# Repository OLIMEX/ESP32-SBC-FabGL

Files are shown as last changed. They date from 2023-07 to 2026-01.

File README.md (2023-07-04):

# ESP32-SBC-FabGL
ESP32-WROVER board working with FabGL library

Software used our fork of FabGL: https://github.com/OLIMEX/FabGL

Product page: https://www.olimex.com/Products/Retro-Computers/ESP32-SBC-FabGL/open-source-hardware

## License
* Hardware is released under CERN OHL v1.2 license
* Software is released under GPL3 License
* Documentation is released under CC BY-SA 3.0

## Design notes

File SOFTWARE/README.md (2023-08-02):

[Firmware_CH32V003](Firmware_CH32V003/) folder contains the source of the firmware preloaded on CH32V003 chip.

[CH32V003_Driver](CH32V003_Driver/) folder contains source of the driver needed to communicate with CH32V003 chip. This driver is used on ESP32 side. Examples of its usage will be uploaded soon.

[FabGL_Nunchuk](FabGL_Nunchuk/) folder contains source of device driver to use WiiNunchuk device with FabGL library. It is in fabgl namespace. Example of its usage can be found in our FabGL fork. It will be pull-requested to Fabio's repository.

[FabGL_PCEmulator](FabGL_PCEmulator/PCEmulator/) folder contains modified source of the PCEmulator application which allows usage of GPIO, I2C and SPI from QBasic and Turbo Pascal 7.0.

[FabGL_Basic](FabGL_Basic/) folder contains source of QBasic examples of usage of GPIOs, I2C and SPI located on UEXT connector. These examples are intended to be used from the PCEmulator application.

[FabGL_Pascal](FabGL_Pascal/) folder contains source of Turbo Pascal 7.0 examples of usage of GPIOs, I2C and SPI located on UEXT connector. These examples are intended to be used from the PCEmulator application.

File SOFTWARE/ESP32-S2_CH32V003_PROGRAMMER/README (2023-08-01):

# Flash ESP32-S2 with CH32v003programmer firmware:
esptool.py -p <PORT> -b 460800 --before=no_reset --after=no_reset write_flash --flash_mode dio --flash_freq 80m --flash_size 4MB 0x1000 ./bootloader.bin 0x10000 ./usb_sandbox.bin 0x8000 ./partition-table.bin

# All bin files were built using sources from:
# https://github.com/cnlohr/esp32s2-cookbook/tree/master/ch32v003programmer

# Flashing CH32V003 using minichlink:
minichlink -w <firmware.bin> 0x08000000 -b

# You can download minichlink from:
# https://github.com/cnlohr/ch32v003fun

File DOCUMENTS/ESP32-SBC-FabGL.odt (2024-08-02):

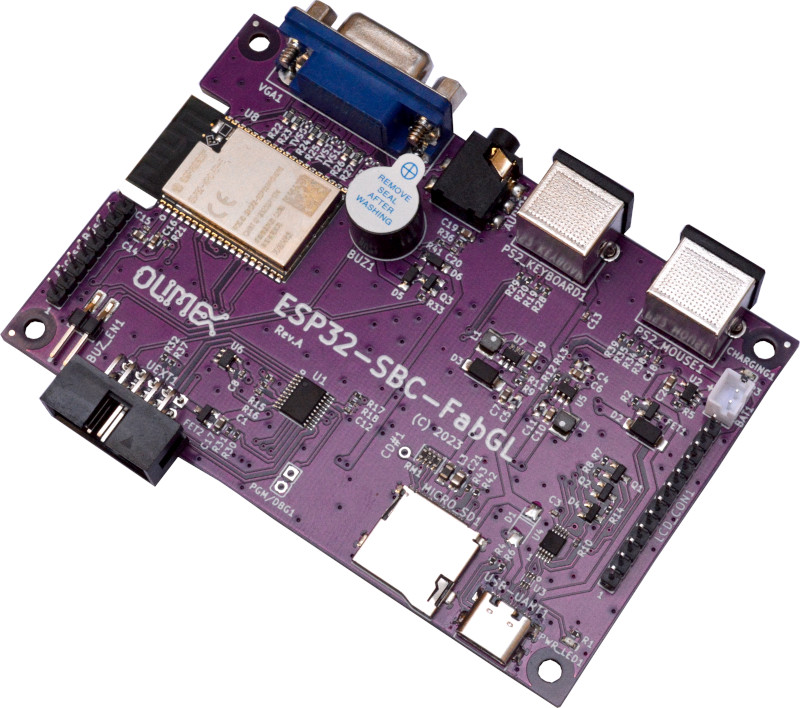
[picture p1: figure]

ESP32-SBC-FabGL

User Manual

Document v3.0 July 2024 olimex.com

# Introduction to ESP32-SBC-FabGL

ESP32-SBC-FabGL (https://www.olimex.com/Products/Retro-Computers/ESP32-SBC-FabGL/open-source-hardware) is Open Source Hardware board designed to work with FabGL library. The board has the following features:

- ESP32-WROVER-E module
- VGA connector
- PS2 keyboard connector
- PS2 mouse connector
- Buzzer
- Audio 3.5mm connector
- AccessBus connector for Serial port master processor
- LCD connector (FabGL support LCD or VGA output)
- CH32V003 co-processor for UEXT port handling
- USB-C power and programming/debug connector
- SY8089A 3.3V 2A (3A peak) DCDC power supply
- Lipo charger and battery connector
- UEXT connector (pUEXT 1.0 mm step connector)
- Dimensions: (104 x 68)mm

## Order codes for ESP32-SBC-FabGL and accessories

ESP32-SBC-FabGL (https://www.olimex.com/Products/Retro-Computers/ESP32-SBC-FabGL/open-source-hardware) FabGL board with VGA keyboard mouse

BOX-ESP32-FabGL (https://www.olimex.com/Products/Retro-Computers/BOX-ESP32-FabGL/) Custom plastic box

CABLE-USB-A-C-1M (https://www.olimex.com/Products/Components/Cables/CABLE-USB-A-C-1M/) USB-C cable 1 meter

BATTERY-LIPO1400mAh (https://www.olimex.com/Products/Power/Lipo-battery/BATTERY-LIPO1400mAh/) Li-po battery 3.7V 1400mAh

UEXT modules (https://www.olimex.com/Products/Modules/) We have temperature, humidity, pressure, magnetic field, light sensors. Modules with LCDs, LED matrix, Relays, Bluetooth, Zigbee, WiFi, GSM, GPS, RFID, RTC, EKG, sensors and etc.

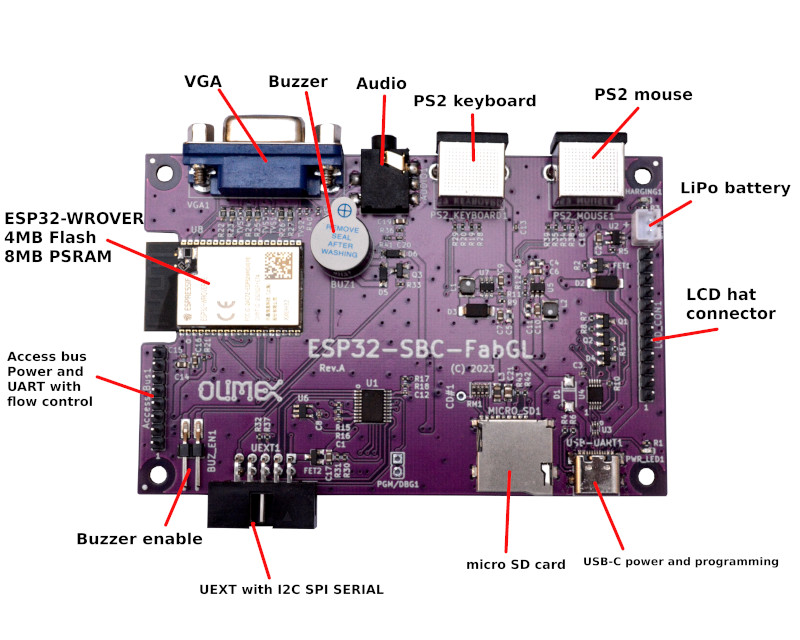
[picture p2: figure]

# HARDWARE

## ESP32-SBC-FabGL schematic and sources

Latest schematic is available on next page for viewing. Sources and PDF export are for ESP32-SBC-FabGL (https://www.olimex.com/Products/Retro-Computers/ESP32-SBC-FabGL/open-source-hardware) are available at GitHub (https://github.com/OLIMEX/ESP32-SBC-FabGL). The page after the schematic shows the dimensions.

At the GitHub pages for the board you can also find schematics for older hardware revisions and also hardware revision change notes (detailing notable changes between revisions).

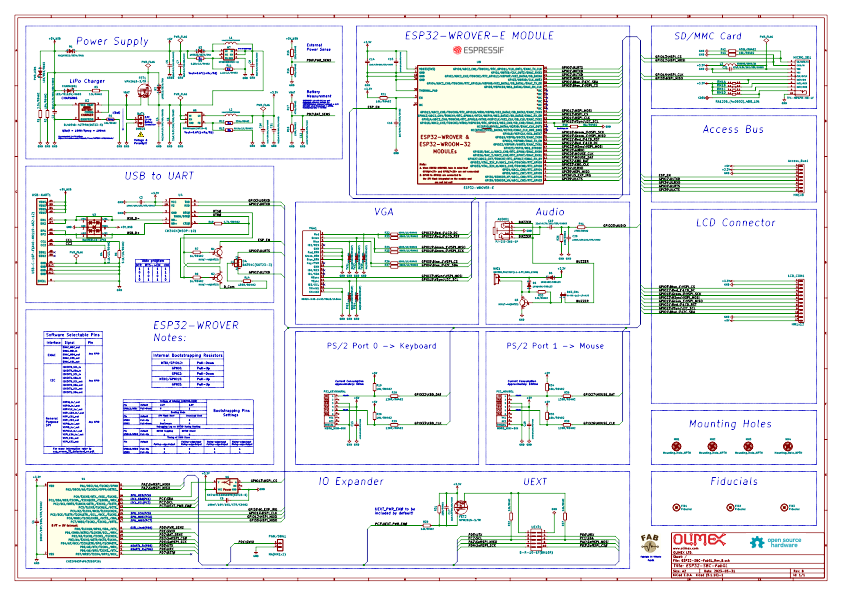
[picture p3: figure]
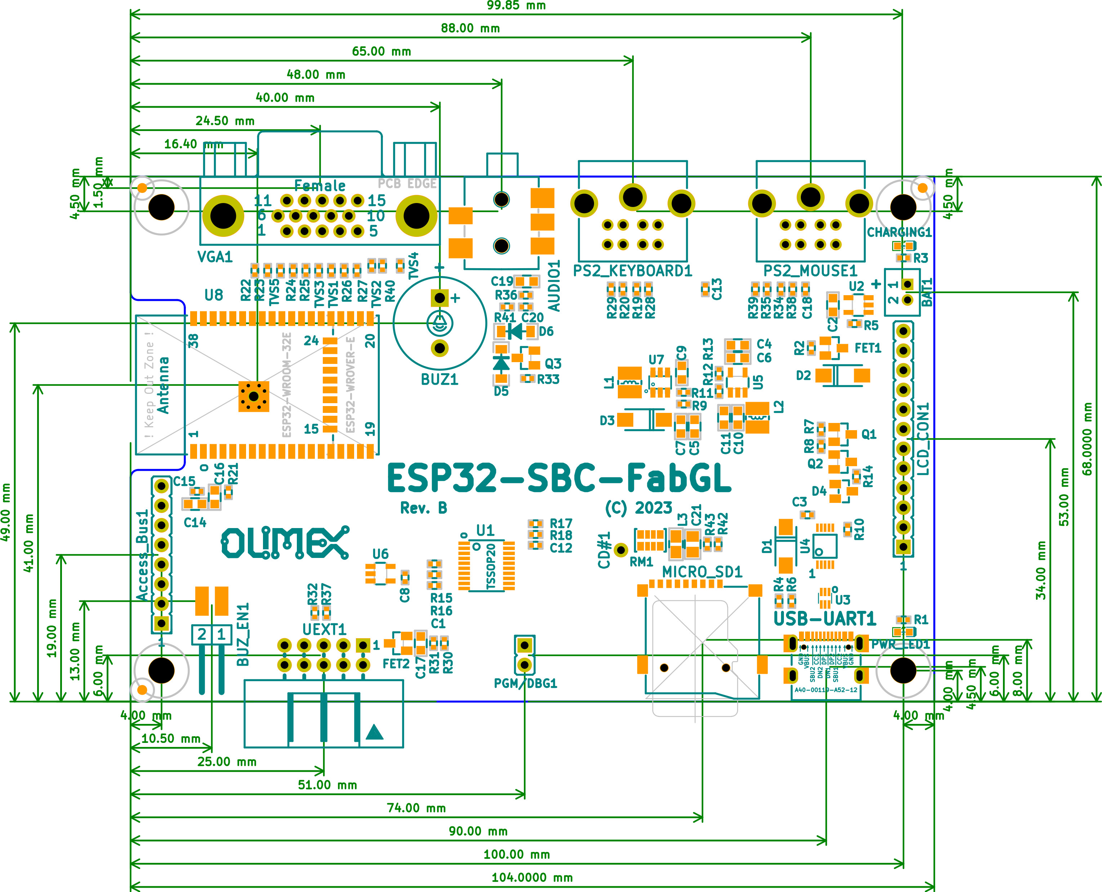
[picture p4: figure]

## UEXT connector:

UEXT connector stands for Universal EXTension connector and contain +3.3V, GND, I2C, SPI, UART signals. UEXT connector can be in different shapes and sizes but the original UEXT connector is 0.1” 2.54mm step boxed plastic connector. All signals are at 3.3V levels.

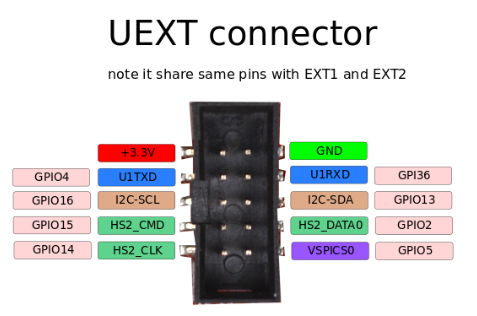
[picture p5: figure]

As the boards become smaller and smaller some smaller packages were introduced (beside the original UEXT connector):

- mUEXT is 1.27 mm step boxed header connector which is with same layout as UEXT

- pUEXT is 1.0 mm single row connector (this is the connector used in RP2040-PICO30)

Olimex has developed number of MODULES (https://www.olimex.com/Products/Modules/) with this connector. There are temperature, humidity, pressure, magnetic field, light sensors. Modules with LCDs, LED matrix, Relays, Bluetooth, Zigbee, WiFi, GSM, GPS, RFID, RTC, EKG, sensors and etc.

## AccessBus connector:

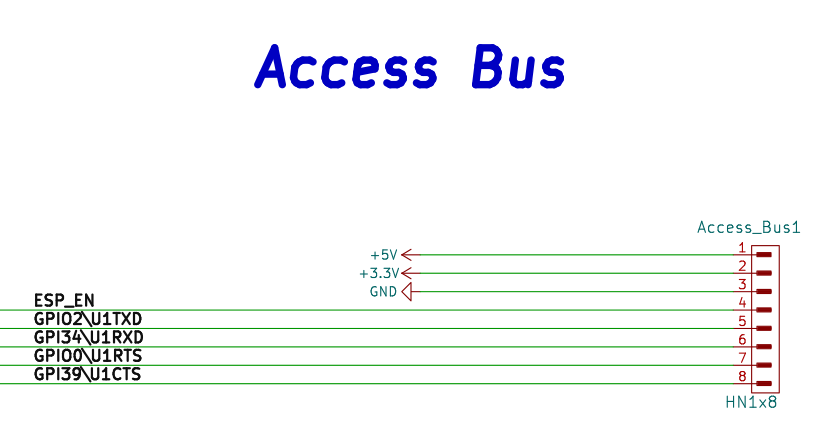
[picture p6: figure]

Pin1. is marked with a square pad, all others are round pads.

## LCD hat connector:

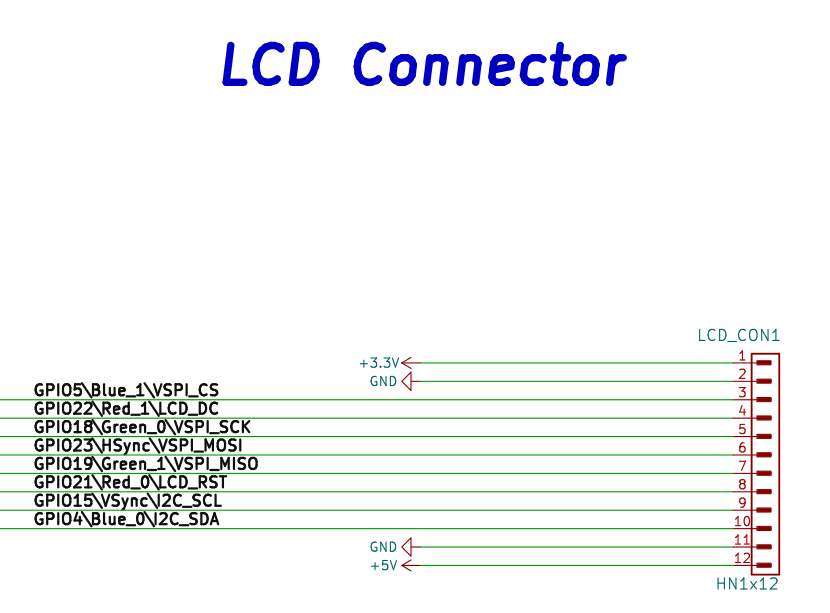
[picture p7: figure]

Pin1. is marked with a square pad, all others are round pads.

# SOFTWARE

ESP32-SBC-FabGL (https://www.olimex.com/Products/Retro-Computers/ESP32-SBC-FabGL/open-source-hardware) is tested and works with many projects, start with the Olimex fork of FabGL project: https://github.com/OLIMEX/FabGL and make sure to check the resources here:

https://github.com/OLIMEX/ESP32-SBC-FabGL/tree/main/SOFTWARE

and here:

https://github.com/OLIMEX/FabGL

## How to get the board working in Arduino IDE?

Set up the Arduino environment

1. Install and start Arduino IDE, get it from: https://www.arduino.cc/en/software

2. Add the esp32 board support by Espressif using the Board Manager (Tools > Board > Board Manager and search for "esp32"). Use the package called “esp32” by Esoressif Systems and use the version selector to load a version 2.x.x! IMPORTANT! At the time of writing this, the FabGL library is NOT compatible with version 3.x.x or newer of the package. From the drop-down menu select version 2.0.x, we used 2.0.11.

3. The Olimex fork of FabGL adds support for the ESP32-SBC-FabGL board and needs to be installed as a local library. You'll also need to first uninstall Fabrizio's FabGL library if it's already installed.

- Go to the Olimex FabGLrepo at GitHub: https://github.com/OLIMEX/FabGL
- Click "Download ZIP" from the green "Code" drop-down button, top-right. Save the ZIP file as "Olimex-FabGL.zip" so you don't get confused with Fabrizio's library and repo.
- Unzip and copy the contents to a new folder in the "Documents\Arduino\libraries" folder (e.g. "C:\Users\username\Documents\Arduino\libraries\Olimex-FabGL").

4. Close Arduino IDE. The next time the IDE is started, the local Olimex FabGL library will be available for use.

Compile and download examples to ESP32-SBC-FabGL

1. Connect the ESP32-SBC-FabGL board to your desktop PC using a USB cable. The USB-C port on the board serves as both power and data.

2. Start Arduino IDE.

3. Verify the Olimex FabGL library is loaded by:
- Opening the Library Manager (Tools > Manage Libraries).
- Typing "FabGL" in to the "filter" textbox.
- Changing the "Type" to "Installed".
- It should list "FabGL 1.0.9" (at the time of this writing) as one of the installed libraries.

4. Select a FabGL demo from (File > Examples > FabGL). The FabGL examples will be at the bottom of a lengthy list.

5. Configure the board.
- Select the "ESP32 Dev Module" board (Tools > Board > esp32 > ESP32 Dev Module).
- Set the board port to upload to (Tools > Port > COM#).
- Set the partition scheme (Tools > Partition > Huge APP).
- Disable PSRAM (Tools > PSRAM > Disabled).
- Set the Upload Speed (Tools > Upload Speed > 921600).
- If an upload error occurs, lower the transfer speed.

6. Edit the demo if needed. Most demos are well-commented on what has to be edited. Some demos require also preparing an SD card or else in specific manner.

7. Compile and upload to the board (Sketch > Upload).

- If all goes well, the ESP32-SBC-FabGL board will reboot after the compilation and upload complete.
- If the wireless parameters were not set, a prompt asking to configure the wireless connection will appear.
- After that, the boot menu should show.

If you have compilation problems with most of the examples you probably installed latest version of espressif package for ESP32. The most important part is to use ESP32 package version older than 3.x.x ESP32 package (we used Espressif 2.0.11). Also do NOT use the “Arduino ESP32 Boards” package! Use the “esp32” package by espressif systems!

## Wordpress articles

Also make sure to check these FabGL articles at our wordpress:

- https://olimex.wordpress.com/2023/06/27/esp32-sbc-fabgl-update-now-you-can-play-invaders-with-wii-nunchuck-via-the-uext-port/

- https://olimex.wordpress.com/2023/08/01/esp32-sbc-fabgl-how-to-work-with-the-expander-module-gpios-from-fabgl-library-and-apps/

- https://olimex.wordpress.com/2023/05/31/zx-espectrum-emulator-tested-with-esp32-sbc-fabgl-the-mensch-computer-with-w65c256-got-vga-display-and-keyboard/

- https://olimex.wordpress.com/2023/05/25/new-open-source-hardware-design-is-verified-esp32-sbc-fabgl-single-board-computer-based-on-fabgl-library-with-ps2-keyboard-mo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

Other projects that we haven’t tested fully but should work:

https://github.com/uho/ESP32forthStation

https://github.com/OulanB/OricVGA32

https://github.com/guidol70/RunCPM_VGA32

https://github.com/EremusOne/ZX-ESPectrum-IDF

https://github.com/rpsubc8/ESP32TinyMCUMEesp81

https://github.com/rpsubc8/ESP32TinyNesMaster

https://github.com/rpsubc8/ESP32TinyZXSpectrum

https://github.com/rpsubc8/ESP32TinyFairChild

https://github.com/rpsubc8/ESP32TinyChip8

https://github.com/rpsubc8/ESP32TinyFake86

https://github.com/rpsubc8/ESP32TinyCPC

https://github.com/rpsubc8/ESP32TinyC64

# Document revision history

Revision 1.0 May 2023

Revision 2.0 April 2024

Revision 3.0 July 2024

- added Arduino IDE installation instructions

- added dimensions

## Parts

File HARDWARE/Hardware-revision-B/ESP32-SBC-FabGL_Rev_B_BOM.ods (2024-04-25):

Qty | Designation | Package | Designator
4 | 120R/R0402 | R_0402_5MIL_DWS | R28,R29,R38,R39
2 | 150R/R0402 | R_0402_5MIL_DWS | R14,R36
1 | 270R/R0402 | R_0402_5MIL_DWS | R41
3 | 430R/1%/R0402 | R_0402_5MIL_DWS | R22,R24,R26
3 | 866R/1%/R0402 | R_0402_5MIL_DWS | R23,R25,R27
2 | 1k/R0402 | R_0402_5MIL_DWS | R7,R8
1 | 1.1k/1%/R0402 | R_0402_5MIL_DWS | R11
6 | 2.2k/R0402 | R_0402_5MIL_DWS | R1,R3,R30,R32,R37,R33
1 | 4.7k/R0402 | R_0402_5MIL_DWS | R10
2 | 5.1k/1%/R0402 | R_0402_5MIL_DWS | R4,R6
1 | 8.25k/1%/R0402 | R_0402_5MIL_DWS | R9
8 | 10k/R0402 | R_0402_5MIL_DWS | R2,R5,R19,R20,R21,R34,R35,R43
1 | 49.9k/1%/R0402 | R_0402_5MIL_DWS | R13
1 | 150k/R0402 | R_0402_5MIL_DWS | R18
3 | 220k/R0402 | R_0402_5MIL_DWS | R12,R15,R31
3 | 470k/R0402 | R_0402_5MIL_DWS | R16,R17,R42
1 | RA1206_(4x0603)_4B8_10k | RA1206_(4X0603)_4B8_xx | RM1
8 | 100nF/10V/10%/X7R/C0402 | C_0402_5MIL_DWS | C1,C3,C8,C12,C13,C15,C18,C20
1 | 1uF/10V/20%/X5R/C0603 | C_0603_5MIL_DWS | C16
8 | 22uF/6.3V/20%/X5R/C0603 | C_0603_5MIL_DWS | C2,C6,C7,C9,C10,C14,C17,C19
1 | 47uF/6.3V/20%/X5R/C0805 | C_0805_5MIL_DWS | C21
1 | 2.2uH/NRS3015T2R2MNGH | CD32 | L1,L2
1 | FB0805/600R/2A | L_0805_5MIL_DWS | L3
2 | 1N5822/SS34/SMA | SMA-KA | D2,D3
2 | 1N4148W/SOD123 | SOD-123_1C-2A_KA | D5,D6
1 | BAT54C(SOT23-3) | SOT23-3 | D4
1 | LED/RED/0603 | LED_0603_KA | PWR_LED1
1 | LED/YELLOW/0603 | LED_0603_KA | CHARGING1
3 | BC817-40(SOT23) | SOT23 | Q1,Q2,Q3
2 | WPM2015-3/TR | SOT23 | FET1,FET2
1 | CH32V003F4P6(TSSOP20) | TSSOP20_Pitch-0.65mm_6.6x4.5x1.2mm | U1
1 | BL4054B-42TPRN(SOT23-5) | SOT-23-5 | U2
1 | CH340X(MSOP-10) | MSOP-10_Pitch-0.5mm_3.00x3.00x1.00mm | U4
1 | SY8089AAAC(SOT23-5) | SOT-23-5 | U5
1 | MT3608(SOT23-6) | SOT23-6 | U7
1 | ESP32-WROVER-E | ESP32-WROVER)-UNIVERSAL_MODULE | U8
1 | SN74LVC1G04DBVR(SOT23-5) | SOT-23-5 | U6
1 | PJ-3.5-365-5P | SCJ325P00XG0B02G | AUDIO1
1 | DW02S | LIPO_BAT_VERTICAL_DW02S | BAT1
1 | BUZZER_PB1221P (1.1-1.7V_2kHz_12MM) | PB1221P_1-Plus_2-Minus | BUZ1
1 | TFC-WPAPR-08-LF | TFC-WPAPR-08 | MICRO_SD1
2 | MDR6_MINI-DIN | PS2_MDR6_MINI-DIN | PS2_KEYBOARD1,PS2_MOUSE1
1 | HDR15-3.08-14.5T/VGA15/14.5mm | VGA15-F(HDR15-3.08-14.5T) | VGA1
1 | USB-C-16P-F(A40-00119-A52-12) | USB2.0_TYPE-C(A40-00119-A52-12)_Paste | USB-UART1
1 | B-R-10-LF(BH10R) | BH10R | UEXT1
1 | HN1x8 | HN1x8 | Access_Bus1
1 | HN1x12 | HN1x12 | LCD_CON1
1 | H-WX-1x2-LF+MJ6 | HN1x2(SMD)_H-WX-1x2-LF | BUZ_EN1
3 | NA(22uF/6.3V/20%/X5R/C0603) | C_0603_5MIL_DWS | C11,C4,C5
5 | NA(GG0402052R542P) | D_0402_5MIL_DWS | TVS1,TVS2,TVS3,TVS4,TVS5
1 | NA(USBLC6-2P6) | SOT-666 | U3
1 | NA(HN1x2) | HN1x2 | PGM/DBG1
1 | NA(1N5822/SS34/SMA) | SMA-KA | D1
1 | NA/R0402 | R_0402_5MIL_DWS | R40

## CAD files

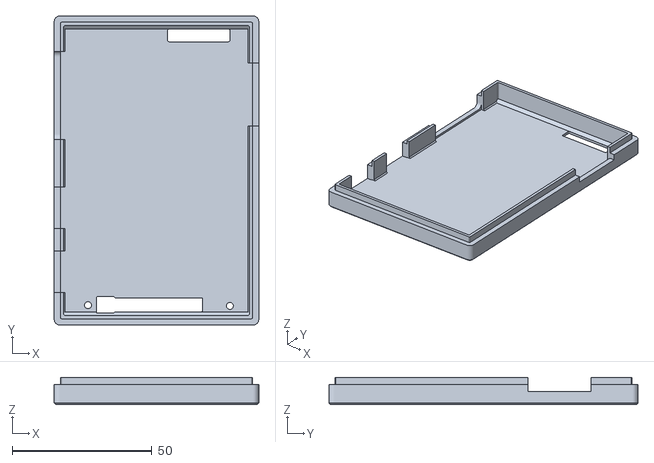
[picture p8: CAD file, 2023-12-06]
HARDWARE/3D printed case/esp32-sbc-fabgl-revsion-A-top-v1.stl
73.1 x 110.4 x 9.80

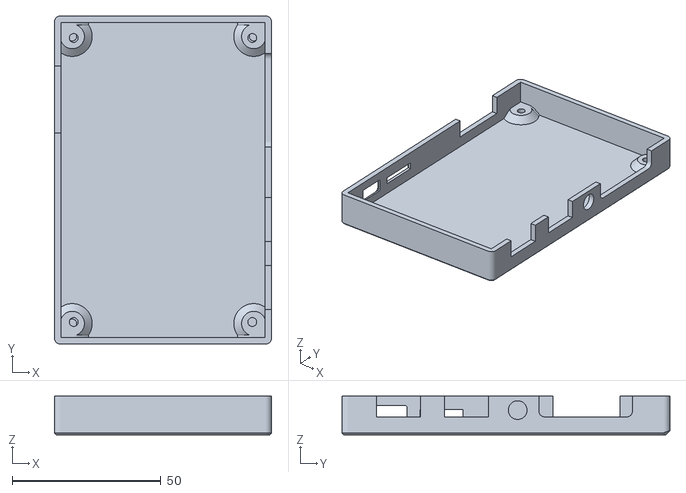
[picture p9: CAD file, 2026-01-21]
HARDWARE/3D printed case/olimex-esp32-fabgl-model_files/esp32-sbc-fabgl_v1-bottom.stl
73.1 x 110.4 x 13.0

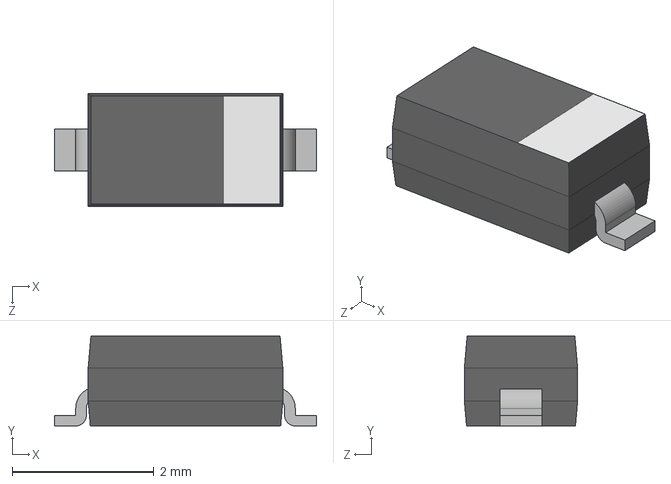
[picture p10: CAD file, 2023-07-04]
HARDWARE/Hardware-revision-B/3d/SOD123.step
3.70 x 1.27 x 1.60 mm

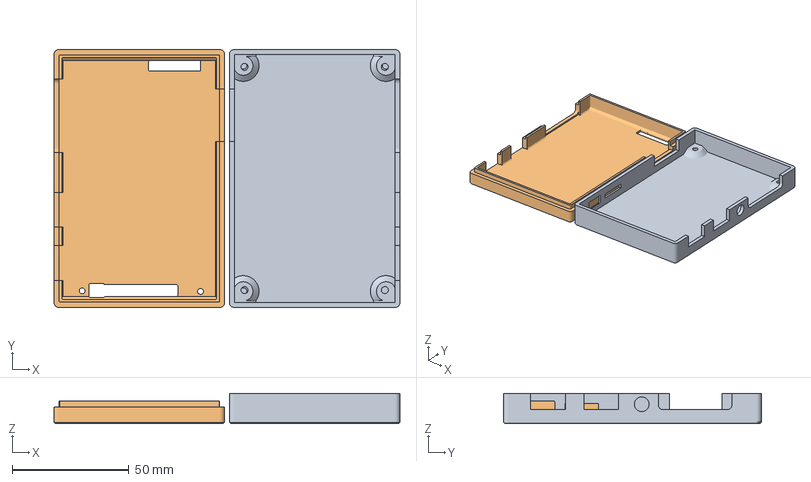
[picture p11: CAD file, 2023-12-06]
HARDWARE/3D printed case/esp32-sbc-fabgl-revsion-A-v1.3mf
148.2 x 110.4 x 13.0 mm
bottom (1) (1)
top (2)

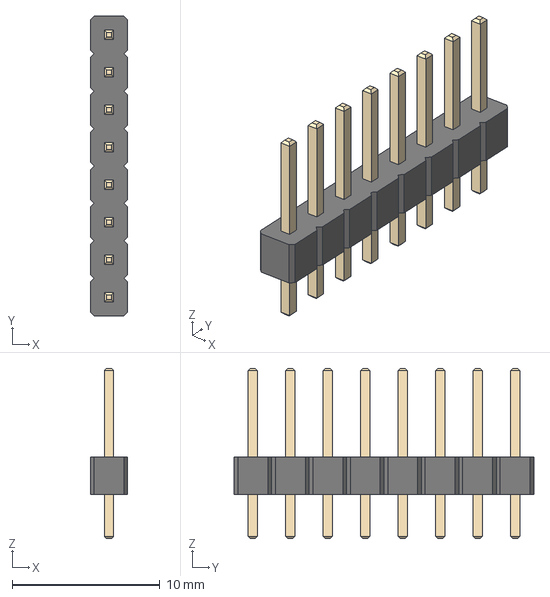
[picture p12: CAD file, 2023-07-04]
HARDWARE/Hardware-revision-B/3d/HN1x8-PinHeader_1x08_P2.54mm_Vertical.step
2.54 x 20.3 x 11.5 mm

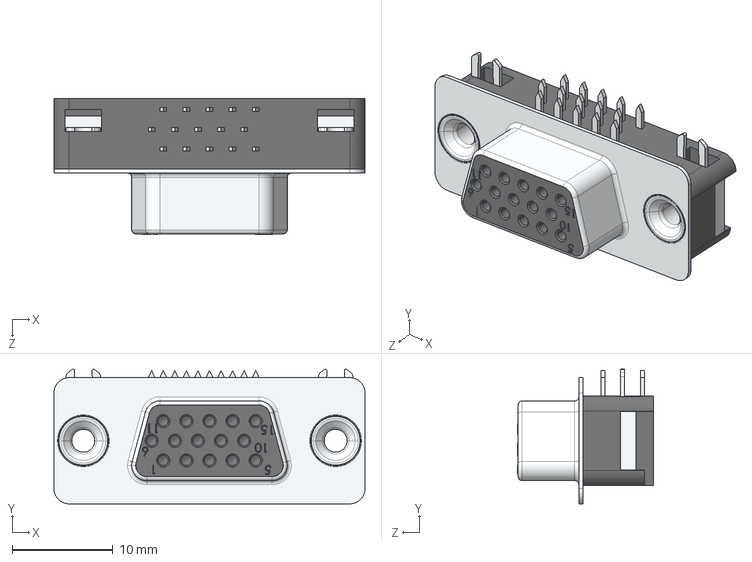
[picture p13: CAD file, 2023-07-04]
HARDWARE/Hardware-revision-B/3d/User Library-SLIM D-SUB RIGHT ANGLE PCB MOUNT.step
30.8 x 13.3 x 13.5 mm

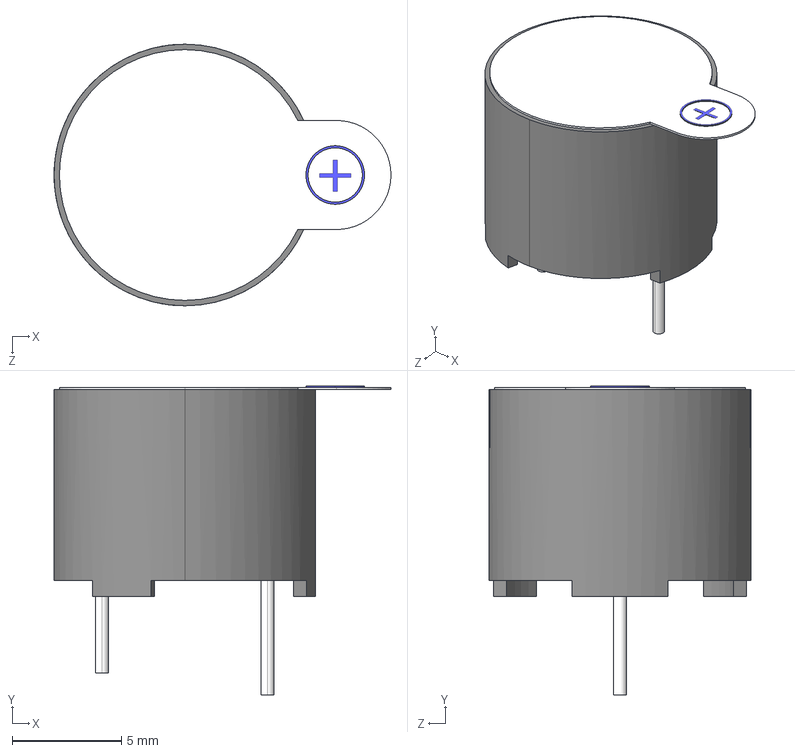
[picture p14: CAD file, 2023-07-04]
HARDWARE/Hardware-revision-B/3d/ALSRobot-BUZZER.step
15.5 x 14.2 x 12.0 mm

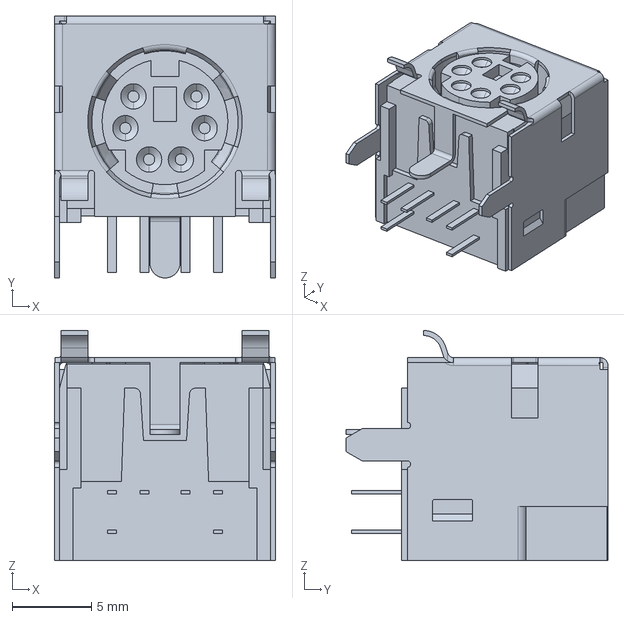
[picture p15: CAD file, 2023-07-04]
HARDWARE/Hardware-revision-B/3d/PS2_MDR6_MINI-DIN(5750071-1).stp
14.0 x 16.6 x 14.5 mm

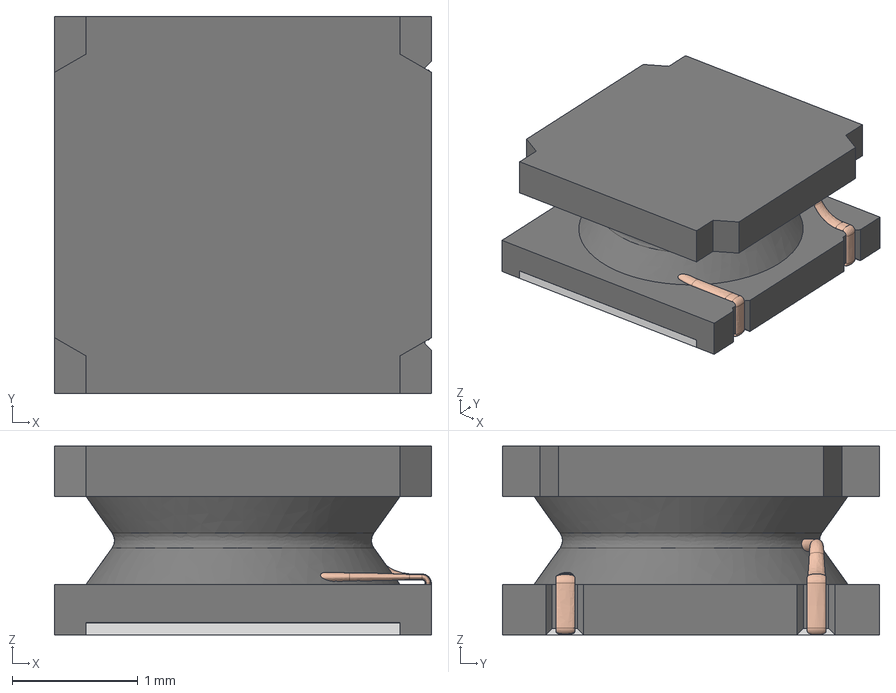
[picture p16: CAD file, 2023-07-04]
HARDWARE/Hardware-revision-B/3d/L-CD32_shielded.step
3.00 x 3.00 x 1.50 mm

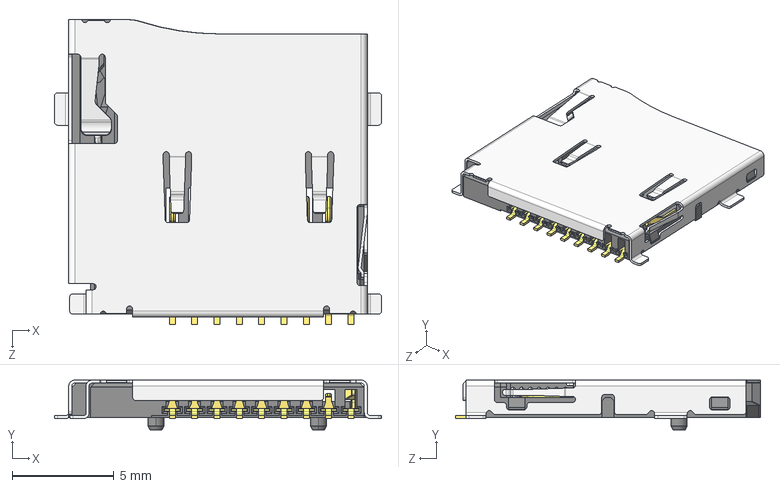
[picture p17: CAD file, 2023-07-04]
HARDWARE/Hardware-revision-B/3d/TFC-WPAPR-08---112J-TXAR-R_C_1-1.STEP
16.1 x 2.45 x 15.0 mm

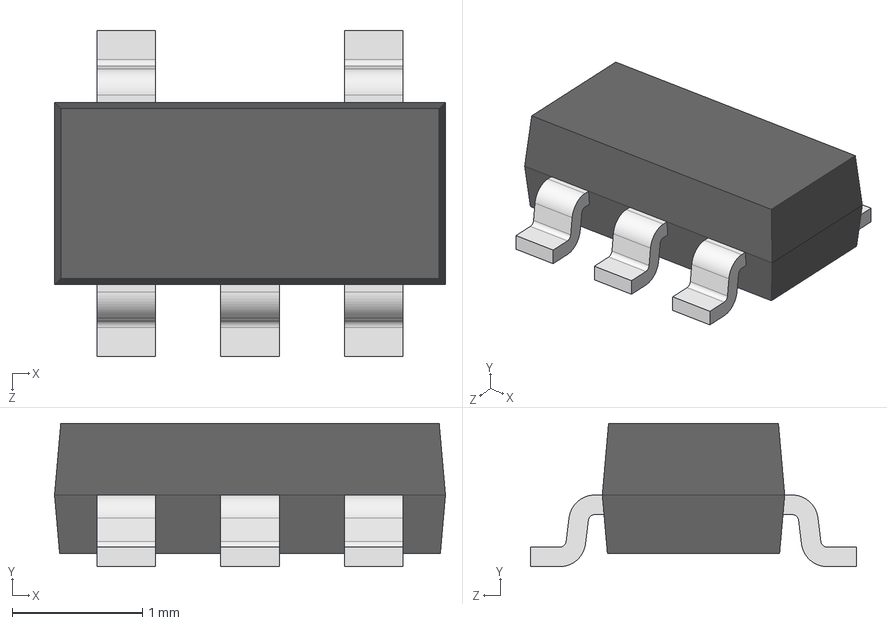
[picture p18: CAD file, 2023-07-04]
HARDWARE/Hardware-revision-B/3d/SOT-23-5.step
3.00 x 1.10 x 2.50 mm

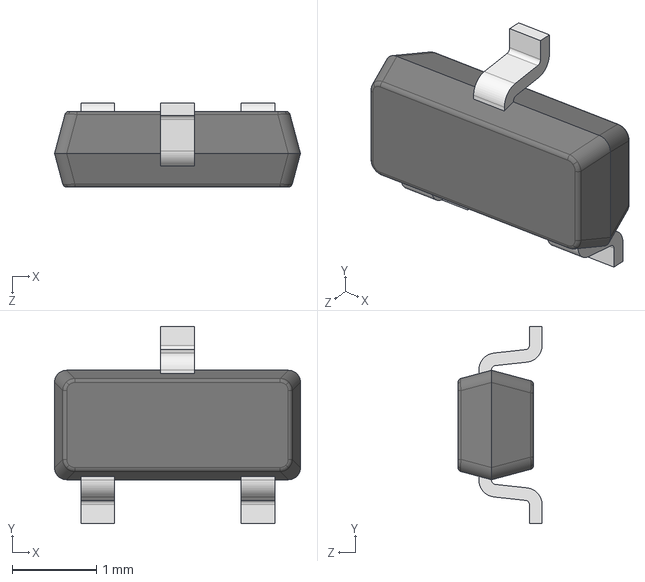
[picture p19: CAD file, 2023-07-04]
HARDWARE/Hardware-revision-B/3d/BAT54.step
2.92 x 2.34 x 1.00 mm

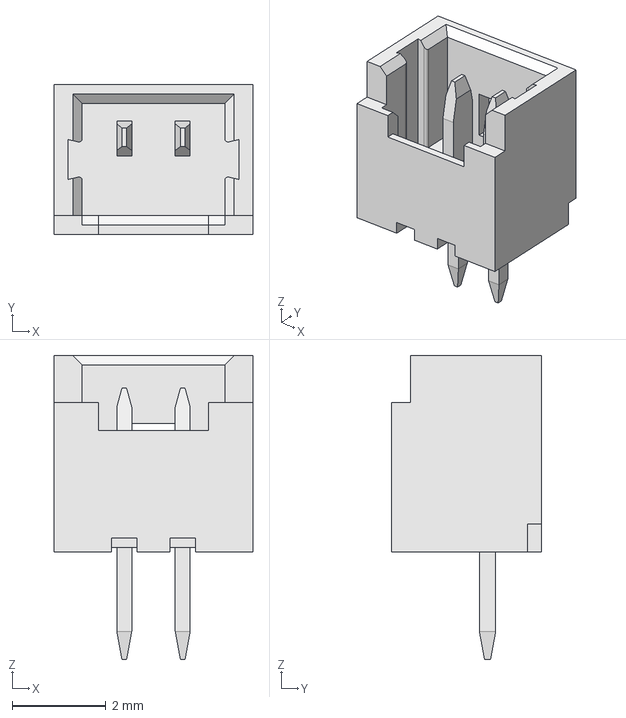
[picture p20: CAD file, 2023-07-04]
HARDWARE/Hardware-revision-B/3d/Molex_PicoBlade_530470210.step
4.25 x 3.20 x 6.50 mm

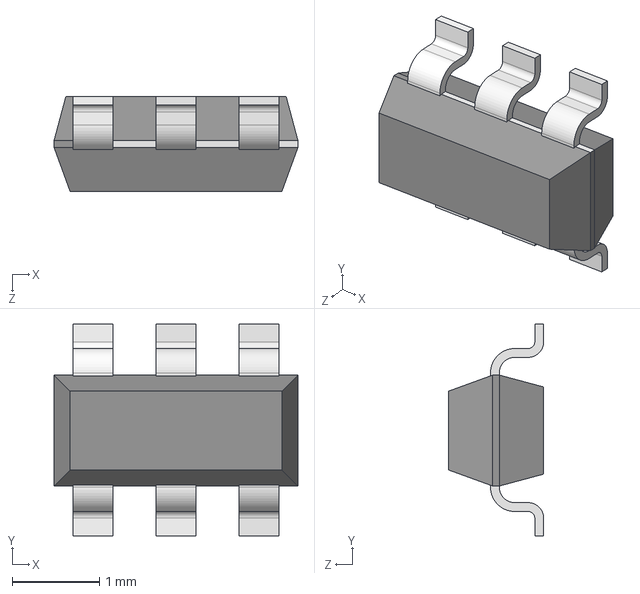
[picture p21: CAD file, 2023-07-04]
HARDWARE/Hardware-revision-B/3d/SOT-23-6.step
2.79 x 2.43 x 1.09 mm

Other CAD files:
HARDWARE/3D printed case/olimex-esp32-fabgl-model_files/esp32-sbc-fabgl_v1-single.3mf
HARDWARE/3D printed case/esp32-sbc-fabgl-revsion-A-bottom-v1.stl
HARDWARE/3D printed case/olimex-esp32-fabgl-model_files/esp32-sbc-fabgl_v1-top.stl
HARDWARE/Hardware-revision-B/3d/DO-214AC_SMA.step
HARDWARE/Hardware-revision-A/3d/Audio_Jack-3.5mm---CUI_SJ1-3515-SMT-TR.step
HARDWARE/Hardware-revision-A/3d/DO-214AC_SMA.step
HARDWARE/Hardware-revision-A/3d/ESP32-WROOM-32D-56544.STEP
HARDWARE/Hardware-revision-A/3d/ESP32-WROVER-I-56544.STEP
HARDWARE/Hardware-revision-A/3d/HN1x12-PinHeader_1x12_P2.54mm_Vertical.step
HARDWARE/Hardware-revision-A/3d/HN1x2-PinHeader_1x02_P2.54mm_Vertical.step
HARDWARE/Hardware-revision-A/3d/Header_right_angle_10way(2x5).step
HARDWARE/Hardware-revision-A/3d/MSOP10-1.step
HARDWARE/Hardware-revision-A/3d/SOT-23.step
HARDWARE/Hardware-revision-A/3d/User Library-SOT50P160X60-6.step
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

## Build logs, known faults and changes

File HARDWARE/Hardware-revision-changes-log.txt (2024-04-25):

Notable hardware changes for ESP32-SBC-FabGL

Notice that the board is designed with KiCAD

---
Hardware revision B (minor changes):

- Added description of Access, Bus, UEXT, and LCD connectors;
- Changed packages of 820R and 430R to 0402;
- Changed value of ESP32 chip to ESP32-WROVER-E;
- Speaker  govoritelq se запазва се като на AgonLight2.
- Improved VGA resistor values 430R changed to 1%.

Hardware revision A:

- initial release

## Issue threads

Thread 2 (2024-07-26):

SpaceInvaders example for ESP32-SBC-FabGL doesn't compile - multiple errors

Andy2No, 2024-07-26:
In trying to compile the SpaceInvaders FabGL example in Arduino 1.8.19, I get multiple errors.  Possibly this is because it's not compatible with ESP Espessif board support v3.0.2, which is the current version.

I started trying to use the main FabGL library, having followed instructions to install that.  I
realised earlier I should have been using Olimex's own fork, so I installed that instead, but that hasn't got me any further.

In order to get the SpaceInvaders.ino example to compile past a certain point, I had to add some missing files, which I've taken from a pending pull request I found in the main FabGL library (now a year old) to add support for the ESP32-SBC-FabGL.  I copied these files into the project folder:

 wiiNunchuk.h, wiiNunchuk.cpp, CH32V003.h, CH32V003.cpp

I got them from here:

https://github.com/fdivitto/FabGL/pull/338

I now get the errors below, which seem to suggest that your example and possibly FabGL fork aren't compatible with ESP 3.0.2 - and it seems neither is the main FabGL library.  The one I bought came with SpaceInvaders isntalled, so I know it's possible, but I can't find any clues how to get it to compile, specifically which versions to use.  I tried ESP v2.0.17 in the boards manager, but that removed support for the ESP32-SBC-FabGL board.  I'm now wondering if it's still even possible to compile FabGL examples, justifying the FabGL part of the name.

Here are the error messages.  Let me know if you need the full compilation log:

```
D:\Documents\Arduino\libraries\FabGL-master\src\fabutils.cpp: In function 'void fabgl::configureGPIO(gpio_num_t, gpio_mode_t)':
D:\Documents\Arduino\libraries\FabGL-master\src\fabutils.cpp:203:19: error: 'GPIO_PIN_MUX_REG' was not declared in this scope; did you mean 'GPIO_PIN19_REG'?
  203 |   PIN_FUNC_SELECT(GPIO_PIN_MUX_REG[gpio], PIN_FUNC_GPIO);
      |                   ^~~~~~~~~~~~~~~~
      |                   GPIO_PIN19_REG
D:\Documents\Arduino\libraries\FabGL-master\src\fabutils.cpp:203:43: error: 'PIN_FUNC_GPIO' was not declared in this scope
  203 |   PIN_FUNC_SELECT(GPIO_PIN_MUX_REG[gpio], PIN_FUNC_GPIO);
      |                                           ^~~~~~~~~~~~~
D:\Documents\Arduino\libraries\FabGL-master\src\fabui.cpp: In member function 'void fabgl::uiApp::killTimer(fabgl::uiTimerHandle)':
D:\Documents\Arduino\libraries\FabGL-master\src\fabui.cpp:948:50: error: invalid conversion from 'fabgl::uiTimerHandle' {aka 'void*'} to 'TimerHandle_t' {aka 'tmrTimerControl*'} [-fpermissive]
  948 |   auto dest = (uiEvtHandler *) pvTimerGetTimerID(handle);
      |                                                  ^~~~~~
      |                                                  |
      |                                                  fabgl::uiTimerHandle {aka void*}
In file included from D:\Documents\Arduino\libraries\FabGL-master\src\fabui.cpp:28:
C:\Users\andy\AppData\Local\Arduino15\packages\esp32\tools\esp32-arduino-libs\idf-release_v5.1-bd2b9390ef\esp32/include/freertos/FreeRTOS-Kernel/include/freertos/timers.h:395:47: note:   initializing argument 1 of 'void* pvTimerGetTimerID(TimerHandle_t)'
  395 | void * pvTimerGetTimerID( const TimerHandle_t xTimer ) PRIVILEGED_FUNCTION;
      |                           ~~~~~~~~~~~~~~~~~~~~^~~~~~
D:\Documents\Arduino\libraries\FabGL-master\src\fabui.cpp:949:44: error: no matching function for call to 'std::pair<fabgl::uiEvtHandler*, tmrTimerControl*>::pair(fabgl::uiEvtHandler*&, void*&)'
  949 |   m_timers.remove(uiTimerAssoc(dest, handle));
      |                                            ^
In file included from c:\users\andy\appdata\local\arduino15\packages\esp32\tools\esp-x32\2302\xtensa-esp32-elf\include\c++\12.2.0\bits\stl_algobase.h:64,
                 from c:\users\andy\appdata\local\arduino15\packages\esp32\tools\esp-x32\2302\xtensa-esp32-elf\include\c++\12.2.0\bits\specfun.h:45,
                 from c:\users\andy\appdata\local\arduino15\packages\esp32\tools\esp-x32\2302\xtensa-esp32-elf\include\c++\12.2.0\cmath:1935,
                 from c:\users\andy\appdata\local\arduino15\packages\esp32\tools\esp-x32\2302\xtensa-esp32-elf\include\c++\12.2.0\math.h:36,
                 from C:\Users\andy\AppData\Local\Arduino15\packages\esp32\hardware\esp32\3.0.2\cores\esp32/esp32-hal.h:30,
                 from C:\Users\andy\AppData\Local\Arduino15\packages\esp32\hardware\esp32\3.0.2\cores\esp32/Arduino.h:36,
                 from D:\Documents\Arduino\libraries\FabGL-master\src\fabutils.h:51,
                 from D:\Documents\Arduino\libraries\FabGL-master\src\fabui.cpp:34:
c:\users\andy\appdata\local\arduino15\packages\esp32\tools\esp-x32\2302\xtensa-esp32-elf\include\c++\12.2.0\bits\stl_pair.h:297:9: note: candidate: 'template<class _U1, class _U2>  requires  _S_constructible<_U1, _U2>() constexpr std::pair<_T1, _T2>::pair(std::pair<_U1, _U2>&&) [with _U2 = _U1; _T1 = fabgl::uiEvtHandler*; _T2 = tmrTimerControl*]'
  297 |         pair(pair<_U1, _U2>&& __p)
      |         ^~~~
c:\users\andy\appdata\local\arduino15\packages\esp32\tools\esp-x32\2302\xtensa-esp32-elf\include\c++\12.2.0\bits\stl_pair.h:297:9: note:   template argument deduction/substitution failed:
D:\Documents\Arduino\libraries\FabGL-master\src\fabui.cpp:949:44: note:   mismatched types 'std::pair<_T1, _T2>' and 'fabgl::uiEvtHandler*'
  949 |   m_timers.remove(uiTimerAssoc(dest, handle));
      |                                            ^
c:\users\andy\appdata\local\arduino15\packages\esp32\tools\esp-x32\2302\xtensa-esp32-elf\include\c++\12.2.0\bits\stl_pair.h:288:9: note: candidate: 'template<class _U1, class _U2>  requires  _S_constructible<const _U1&, const _U2&>() constexpr std::pair<_T1, _T2>::pair(const std::pair<_U1, _U2>&) [with _U2 = _U1; _T1 = fabgl::uiEvtHandler*; _T2 = tmrTimerControl*]'
  288 |         pair(const pair<_U1, _U2>& __p)
      |         ^~~~
c:\users\andy\appdata\local\arduino15\packages\esp32\tools\esp-x32\2302\xtensa-esp32-elf\include\c++\12.2.0\bits\stl_pair.h:288:9: note:   template argument deduction/substitution failed:
D:\Documents\Arduino\libraries\FabGL-master\src\fabui.cpp:949:44: note:   mismatched types 'const std::pair<_T1, _T2>' and 'fabgl::uiEvtHandler*'
  949 |   m_timers.remove(uiTimerAssoc(dest, handle));
      |                                            ^
c:\users\andy\appdata\local\arduino15\packages\esp32\tools\esp-x32\2302\xtensa-esp32-elf\include\c++\12.2.0\bits\stl_pair.h:279:9: note: candidate: 'template<class _U1, class _U2>  requires  _S_constructible<_U1, _U2>() constexpr std::pair<_T1, _T2>::pair(_U1&&, _U2&&) [with _U2 = _U1; _T1 = fabgl::uiEvtHandler*; _T2 = tmrTimerControl*]'
  279 |         pair(_U1&& __x, _U2&& __y)
      |         ^~~~
c:\users\andy\appdata\local\arduino15\packages\esp32\tools\esp-x32\2302\xtensa-esp32-elf\include\c++\12.2.0\bits\stl_pair.h:279:9: note:   template argument deduction/substitution failed:
c:\users\andy\appdata\local\arduino15\packages\esp32\tools\esp-x32\2302\xtensa-esp32-elf\include\c++\12.2.0\bits\stl_pair.h:279:9: note: constraints not satisfied
c:\users\andy\appdata\local\arduino15\packages\esp32\tools\esp-x32\2302\xtensa-esp32-elf\include\c++\12.2.0\bits\stl_pair.h: In substitution of 'template<class _U1, class _U2>  requires  _S_constructible<_U1, _U2>() constexpr std::pair<fabgl::uiEvtHandler*, tmrTimerControl*>::pair(_U1&&, _U2&&) [with _U1 = fabgl::uiEvtHandler*; _U2 = tmrTimerControl*]':
D:\Documents\Arduino\libraries\FabGL-master\src\fabui.cpp:949:44:   required from here
c:\users\andy\appdata\local\arduino15\packages\esp32\tools\esp-x32\2302\xtensa-esp32-elf\include\c++\12.2.0\bits\stl_pair.h:279:2:   required by the constraints of 'template<class _T1, class _T2> template<class _U1, class _U2>  requires  _S_constructible<_U1, _U2>() constexpr std::pair<_T1, _T2>::pair(_U1&&, _U2&&)'
c:\users\andy\appdata\local\arduino15\packages\esp32\tools\esp-x32\2302\xtensa-esp32-elf\include\c++\12.2.0\bits\stl_pair.h:277:45: note: the expression '_S_constructible<_U1, _U2>() [with _U1 = fabgl::uiEvtHandler*&; _U2 = void*&; _T1 = fabgl::uiEvtHandler*; _T2 = tmrTimerControl*]' evaluated to 'false'
  277 |         requires (_S_constructible<_U1, _U2>())
      |                  ~~~~~~~~~~~~~~~~~~~~~~~~~~~^~~
c:\users\andy\appdata\local\arduino15\packages\esp32\tools\esp-x32\2302\xtensa-esp32-elf\include\c++\12.2.0\bits\stl_pair.h:217:9: note: candidate: 'template<class ... _Args1, unsigned int ..._Indexes1, class ... _Args2, unsigned int ..._Indexes2> constexpr std::pair<_T1, _T2>::pair(std::tuple<_Args1 ...>&, std::tuple<_Args2 ...>&, std::_Index_tuple<_Indexes1 ...>, std::_Index_tuple<_Indexes2 ...>) [with _Args1 = {_Args1 ...}; unsigned int ..._Indexes1 = {_Indexes1 ...}; _Args2 = {_Args2 ...}; unsigned int ..._Indexes2 = {_Indexes2 ...}; _T1 = fabgl::uiEvtHandler*; _T2 = tmrTimerControl*]'
  217 |         pair(tuple<_Args1...>&, tuple<_Args2...>&,
      |         ^~~~
D:\Documents\Arduino\libraries\FabGL-master\src\fabutils.cpp:203:3: error: 'PIN_FUNC_SELECT' was not declared in this scope
  203 |   PIN_FUNC_SELECT(GPIO_PIN_MUX_REG[gpio], PIN_FUNC_GPIO);
      |   ^~~~~~~~~~~~~~~
c:\users\andy\appdata\local\arduino15\packages\esp32\tools\esp-x32\2302\xtensa-esp32-elf\include\c++\12.2.0\bits\stl_pair.h:217:9: note:   template argument deduction/substitution failed:
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
DanKoloff, 2024-08-01:
Did you stumble upon this:

https://github.com/MrSoxAndShoes/esp32-sbc-fabgl-quick-start

Andy2No, 2024-08-01:
Thanks very much, DanKoloff.  I'm now able to compile the PC Emulator with those settings, and the v2.0.11 of ESP32 boards support recommended there.   I'll try it out later.

The main pieces that were missing from what I've been able to find in this repo were:

```
Espressif 2.0.11
Select the "ESP32 Dev Module" board (Tools > Board > esp32 > ESP32 Dev Module)
```

The Espressif 2.0.11 part being which board support package to select in the Arduino IDE boards manager, and the second part being which board type to choose, when compiling one of the examples (including the PC emulator).

I'd like to suggest that this needs to be added to the documentation for this board, perhaps to the readme pages of the two repos - this one, specifically about this board, and the one for the Olimex fork of FabGL (https://github.com/OLIMEX/FabGL).  Perhaps added to the product page on the Olimex website too, and ideally to the manual.

It seems this problem has been around since at least the release of Espressif 3.0.x, though I'm not clear when that was.  The existing documentation was no doubt fine at the time of release, but the fact that Espressif chose to break support for software written for their earlier versions, means it's no longer enough.

FWIW, in Arduino 1.8.19, it seems necessary to uninstall Espressif 3.0.2 (the current version) before installing 2.0.11.  Possibly it keeps both, otherwise, but shows the greater version number, which is a bit confusing.

DanKoloff, 2024-08-02:
Thank you for the feedback. Some resources were updated, how-to was added in the README here:

https://github.com/OLIMEX/FabGL/blob/master/README.md

and the manual was also updated:

https://github.com/OLIMEX/ESP32-SBC-FabGL/blob/main/DOCUMENTS/ESP32-SBC-FabGL.pdf

Andy2No, 2024-08-02:
You're welcome, @DanKoloff .

Yes, that should do it.  I think the advice to set;

```
Partition Scheme: Huge APP
```

was just for the PC Emulator, but I've tried compiling the SpaceInvaders.ino example with those settings and it works fine, so maybe it doesn't matter for the other examples.  I'll try some more of them soon.

Thanks again.

DanKoloff, 2025-05-04:
Now that I think about it, the issue here was that neither of the official releases are suitable and Olimex version of FabGL had to be used as described here:

https://github.com/OLIMEX/ESP32-SBC-FabGL/issues/4#issuecomment-2829673158

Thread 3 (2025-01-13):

Unable to get Olimex FabGL board to respond on USB-C serial

shawty, 2025-01-13:
I've followed the instructions in the User Guide PDF to get my FabGL board connected to and programmed from my Arduino IDE, but no matter what I try I just keep ending up with this:

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

The device shows up with a proper serial port and no errors in my Device manager:

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

and I have the correct board library:

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

and FabGL version installed into my IDE:

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

Arduino tools menu is as expected:

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

I started at the highest speed, and got slower and slower, but nothing made any difference.

I know that my Arduino IDE as it is set up can program ESP32 boards, as I have 2 standard WRoom32's and an S3 here and I can plug both of those in and program them with no issue.

I've even tried shorting together the "PGM/DBG1" link on the board and re-tested, but again, no matter what, I just get a "No serial response from board"

My board has arrived from PiHut with "Space Invaders" already programmed onto it, and when I try to program the board I see the board re-boot as expected, but it always restarts in space invaders and never uploads my own sketch.

Sketches I'm trying to upload so far as well as my own are the examples from the Olimex Fab32 distro, and all fail the same way.

Any advice?

Andy2No, 2025-01-13:
@shawty You may need to install the driver for the CH340.

Here's a link for Windows 10.  There are other versions:
https://www.arduined.eu/tag/ch340g/

shawty, 2025-01-13:
Hi Andy, I already have that driver installed:

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

I will however grab the latest one I do an update, see if it makes any difference.

Thanks.

DanKoloff, 2025-01-13:
This is the place to get the driver for Windows:

https://www.wch-ic.com/downloads/CH341SER_ZIP.html

Might be bad cable/connectors/USB port - try with another, shorter, better cable and another USB port. Avoid splitters, USB hubs, long cables. Other boards might require less current so that'd explain why they'd work.

shawty, 2025-01-13:
Yes, that was the link I got the original drivers I'm using from.

Already tried different USB ports, but will try again tomorrow.

Cable and Port combo being used with this device, work perfectly fine with all other ESP32 boards I have however.

Will try different cables tomorrow however.

DanKoloff, 2025-01-14:
I am now comparing your setup with mine and I have pre-2.0 Arduino IDE, I use 1.8.19, not sure if that might be the problem but Arduino IDE 2.x introduced is very different and there might be some incompatiblity.

When I plug the board the red PWR_LED1 turns on, the yellow CHARGING1 led turns on and  I get the buzzer playing a renditions of "Prodigy - Invaders Must Die" and when I inspect the entry in "Windows Device Manager" it looks like this:

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

DanKoloff, 2025-01-14:
Log looks like this, I tested with latest pre 3.x version of the ESP32 library (2.0.17), it seems to compile fine:

`Using library Preferences at version 2.0.0 in folder: C:\Users\olimex\AppData\Local\Arduino15\packages\esp32\hardware\esp32\2.0.17\libraries\Preferences
Using library FabGL-Olimex-master at version 1.0.9 in folder: C:\Users\olimex\Documents\Arduino\libraries\FabGL-Olimex-master
Using library SPI at version 2.0.0 in folder: C:\Users\olimex\AppData\Local\Arduino15\packages\esp32\hardware\esp32\2.0.17\libraries\SPI
Using library WiFi at version 2.0.0 in folder: C:\Users\olimex\AppData\Local\Arduino15\packages\esp32\hardware\esp32\2.0.17\libraries\WiFi
"C:\\Users\\olimex\\AppData\\Local\\Arduino15\\packages\\esp32\\tools\\xtensa-esp32-elf-gcc\\esp-2021r2-patch5-8.4.0/bin/xtensa-esp32-elf-size" -A "C:\\Users\\olimex\\AppData\\Local\\Temp\\arduino_build_102007/BaseExample.ino.elf"
Sketch uses 438133 bytes (13%) of program storage space. Maximum is 3145728 bytes.
Global variables use 26644 bytes (8%) of dynamic memory, leaving 301036 bytes for local variables. Maximum is 327680 bytes.
C:\Users\olimex\AppData\Local\Arduino15\packages\esp32\tools\esptool_py\4.5.1/esptool.exe --chip esp32 --port COM6 --baud 921600 --before default_reset --after hard_reset write_flash -z --flash_mode dio --flash_freq 80m --flash_size 4MB 0x1000 C:\Users\olimex\AppData\Local\Temp\arduino_build_102007/BaseExample.ino.bootloader.bin 0x8000 C:\Users\olimex\AppData\Local\Temp\arduino_build_102007/BaseExample.ino.partitions.bin 0xe000 C:\Users\olimex\AppData\Local\Arduino15\packages\esp32\hardware\esp32\2.0.17/tools/partitions/boot_app0.bin 0x10000 C:\Users\olimex\AppData\Local\Temp\arduino_build_102007/BaseExample.ino.bin
esptool.py v4.5.1
Serial port COM6
Connecting.....
Chip is ESP32-D0WD-V3 (revision v3.0)
Features: WiFi, BT, Dual Core, 240MHz, VRef calibration in efuse, Coding Scheme None
Crystal is 40MHz
MAC: 44:17:93:e6:1d:a8
Uploading stub...
Running stub...
Stub running...
Changing baud rate to 921600
Changed.
Configuring flash size...
Flash will be erased from 0x00001000 to 0x00005fff...
Flash will be erased from 0x00008000 to 0x00008fff...
Flash will be erased from 0x0000e000 to 0x0000ffff...
Flash will be erased from 0x00010000 to 0x0007bfff...
Compressed 18992 bytes to 13110...
Writing at 0x00001000... (100 %)
Wrote 18992 bytes (13110 compressed) at 0x00001000 in 0.6 seconds (effective 266.8 kbit/s)...
Hash of data verified.
Compressed 3072 bytes to 137...
Writing at 0x00008000... (100 %)
Wrote 3072 bytes (137 compressed) at 0x00008000 in 0.1 seconds (effective 268.4 kbit/s)...
Hash of data verified.
Compressed 8192 bytes to 47...
Writing at 0x0000e000... (100 %)
Wrote 8192 bytes (47 compressed) at 0x0000e000 in 0.2 seconds (effective 381.7 kbit/s)...
Hash of data verified.
Compressed 438496 bytes to 240353...
Writing at 0x00010000... (6 %)
Writing at 0x0001b321... (13 %)
Writing at 0x0002d903... (20 %)
Writing at 0x00034ca9... (26 %)
Writing at 0x0003a0ff... (33 %)
Writing at 0x0003f746... (40 %)
Writing at 0x00044c3e... (46 %)
Writing at 0x0004a077... (53 %)
Writing at 0x0004f543... (60 %)
Writing at 0x00054b92... (66 %)
Writing at 0x0005ba93... (73 %)
Writing at 0x00065272... (80 %)
Writing at 0x0006c8f0... (86 %)
Writing at 0x00071e67... (93 %)
Writing at 0x0007750c... (100 %)
Wrote 438496 bytes (240353 compressed) at 0x00010000 in 4.9 seconds (effective 710.5 kbit/s)...
Hash of data verified.

Leaving...
Hard resetting via RTS pin...
`

shawty, 2025-01-14:
Hi @DanKoloff ,

Yes mine boots up the same way (Came pre-programmed with space invaders) , red goes on, yellow goes on.

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

As I've shown above, mine appears on COM19, Identical driver file to the one your using.

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

To Test the Serial Port I opened it with Putty, it does open, but there is no output:

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

I cannot test to see if there's output during boot, as to reset the board I have to unplug the USB, this means my serial terminal closes, and I cannot physically reconnect it and run the app fast enough before the board boots back into space invaders. (If you know of a way I can reboot the board without unplugging the power that might help)

As I showed above in my first post however:

I'm trying the hardware sketch from the Olimex FabGL

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

I have everything set up as per the PDF:

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

And every time the Arduino IDE (No matter what the sketch is) simply says "there is no response from the ESP32 over the uart)
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
DanKoloff, 2025-01-14:
I didn't change any jumpers. Just connected USB cable.

PGM/DBG1 shouldn't be changed and it is not related to serial communication. It is used to change the IO expander firmware of the chip responsible for it - CH32V003F4P6. Also you attach a programmer there, not short the pads. So if you connected it disconnect it.

Also I checked here and after manufacturing each board gets programmed via USB, and yours has the demo on it (which was uploaded via the USB here), so it was programmed via the USB successfully eat least once. Furthermore if there was hardware problem with the USB of the board there would be some error reported by the driver, or the board wouldn't be visible in the device manager, or LEDs won't turn on or something. But it all looks fine. It is quite unlikely that the issue is with the board.

I still think it is the USB cable or the port. The two boards are not comparable when it comes to power consumption. The ESP32-SBC-FabGL consumes considerably more and a poor cable might have some voltage drop. I'd try with another cable and USB port and maybe even with another computer.

shawty, 2025-01-14:
So I've been trying with a different Computer, and (This is a bit insane, I've never seen anything like it in all the years I've been in this game), but exactly the same version of Arduino, Exactly the same Cable, Exactly the same set-up as on the big PC, and...

I can program the FabGL.

However... here comes the weird bit.

On the Second Computer the COM port was given the number 11, as in COM11, on the Big PC it was Assigned 19 (COM19) as can be seen in the screen shots above.

Out of curiosity on the second PC, I changed the Port number to 19, the same as the Big PC and bam... as soon as I started to try program it, it failed!!!

Just switching back to Big PC now, and going to try forcing the com port number on this one from 19 (It's auto assigned one) to something else, and see what happens.

Stand BY.... I'll let you know.

shawty, 2025-01-14:
Yup, that's the answer.

I've tried this on 3 different PC's with combinations of 2 different cables and all the USB ports on those 3 machines.

On machines where it failed initially, IE: My main PC, changing the port number to anything other than 19 was fine, as soon as it was changed back to 19 it failed.

On machines where it worked fine first time tested, changing the port number to 19 failed, anything else was perfectly fine.

Looking at the used serial ports in the registry, there is nothing special about port 19, and indeed when I use the various NirSoft utilities to clear out ALL the old USB Com port settings/drivers and reinstall from scratch, the same occurs again.

COM19 as the port number and my board doe not respond, anything else and it's fine.

I have no clue, as to the what/why/how/when, and in all my years dealing with PC based faults and other windows related madness, this is the first time I have ever seen a COM port number have this effect on something plugged in via USB.

Anyway, since we seem to have reached a conclusion I'm happy to close this, unless you want to do some more digging and see if we can get an actual answer to why this occurs?

I suspect maybe a driver bug of some kind.  I have a CH341 Eeprom programmer (Same serial chip set) might be interesting to see if that too fails when used on COM19.

DanKoloff, 2025-01-14:
Very interesting indeed, but if I change it to COM19 no such issue appear here (and we use the same driver). Maybe it is esptool bug or Windows bug. It is not caused by other device or software attached to the same COM since the error you get in that case is different (not "exit status 2"). Anyway, glad a solution was found, not sure if worthy analyzing why this problem appears.

shawty, 2025-01-14:
If I discover anything further on this, I'll add it here, even after closed.

I'm the type of person that WILL come back to this, as it will bug me until I figure it out :-)

Andy2No, 2025-01-14:
I've had something similar happen recently with Windows 7 and an STM32.  On certain port numbers it wouldn't work but on others it does.  I have no clear idea either but I had been uninstalling unused drivers to free up port numbers after they climbed into triple digits.  I also used the registry editing trick to stop it marking them as "in use" though, when trying to reassign numbers, which may add to the complication.

Tera Term could appear to connect but not actually receive anything, and it currently has COM12-15 in the list of ports I could choose to connect to, which isn't right because none of those are plugged in.  It seems there's plenty that's unexplained, and it probably hasn't changed significantly in later versions of Windows.

Closed 2025-01-14.

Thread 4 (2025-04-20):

Invalid FQBN: Board esp32:esp32:esp32-sbc-fabgl not found.

JacekRuzyczka, 2025-04-20:
I've got an Olimex-ESP32-FabGL board I'd like to fill with one of the example scripts that come with FabGL, but when trying to compile `KeyoardScanCodes.ino` in the Arduino IDE 2.3.6 (Linux), I first ran into a whole bunch of compiler errors as described in issue #2 and then, after following the advice to downgrade the ESP32 library to version 2.0.17 (previously it was 3.2.0, I think), I can't make the example even start compiling, as I always get such an error message:

```
Invalid FQBN: Board esp32:esp32:esp32-sbc-fabgl not found.
```

The FQBN looks somehow strange to me, as `esp32` is stated three times.

FabGL version is 1.0.9, board name is `OLIMEX-SBC-ESP32-FABGL`, port is `/dev/ttyUSB0`. What's wrong here?

DanKoloff, 2025-04-25:
I double checked today and installed everything on a new computer. There are no issues with compilation if you follow these instructions blindly:

https://github.com/OLIMEX/FabGL?tab=readme-ov-file#how-to-install

Unfortunately, there are many scenarios where things might have gone wrong at your side and I can't explore it all so my advice is to follow the instructions blindly. And if they fail start from scratch (uninstall everything, manually delete Arduino folders that might have been left over undeleted, and install everything anew).

The few important points:

- I used Arduino 1.8.19; ESP32 for Arduino version 2.0.11; Olimex FabGL (not Fabrizio's FabGL, not vdp-gl, it is not installed via Library manager). If in doubt use the same versions of Arduino IDE and ESP32 package for Arduino. Refer to the picture:

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

- You need to use Olimex FabGL. Uninstall everything from "Sketch" - "Include Sketch" - "FabGL" (I guess vdp-gl which you lastly have installed). Both FabGL results should be uninstalled before you proceed. Then install Olimex FabGL, it is not installed from the manager but manually. Download this archive that I used, from here (it is also available at GitHub at the link above, I just renamed it to be more clear):

https://ftp.olimex.com/TEMP/OlimexFABGL/OLIMEX-FABGL.zip

Then from Arudino navigate Sketch -> Include Library -> Add .ZIP library and point to OLIMEX-FABGL.zip that you downloaded. Refer to picture "2-library-add-zip.jpg" on where to find it:

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

Wait until it succeeds. Then restart Arduino IDE.

- Load an example from File -> Examples ->  FabGL, refer to "3-example-load.jpg":
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

- Verify/Compile. It should succeed similar to here, refer to "4-success-compilation.jpg":

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

JacekRuzyczka, 2025-05-03:
I've tried out your solution, but **no use:** ESP32 driver ver. 2.0.11 does **not** work at all with the Arduino 2.3.6 (which is the current version at the time of this writing). After downgrading to 2.0.11, removing the "official" (=Fabrizio's) version of FabGL, and installing the Olimex FabGL from the ZIP file you gave me, I **always** get this error message:

```
Compilation error: Invalid FQBN: Board esp32:esp32:esp32-sbc-fabgl not found.
```

Using the current version (3.2.0) of the ESP32 driver doesn't help either: When I install the Olimex FabGL and then try to compile one of your examples (`KeyboardScancodes.ino`; but the issue is **not** limited to this particular sketch), I get a whole bunch of errors as described in the (now closed) issue #2. In the meantime, I suddenly get the note that version 1.0.9 of the "official" FabGL has been installed without asking me:

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

As you are using version 1.8.19 of the Arduino IDE, I'm afraid that its current version simply no longer supports ver. 2 of the ESP32 driver **and** gives library version from "official" sources priority over those installed manually. May I suggest you to give the current IDE version a try. Thank you.

DanKoloff, 2025-05-04:
So did you try with Arduino 1.8.19 or not? It can be found and downloaded if you scroll down to Legacy IDE releases here:

https://www.arduino.cc/en/software/

JacekRuzyczka, 2025-05-04:
No, so far I haven't even been aware that older versions of the IDE are still available. Shall I try the old version?

Andy2No, 2025-05-04:
@JacekRuzyczka  I'd say yes.  Having appropriate versions of all three components seems to be the key to getting it to work.  I used:

Arduino IDE 1.8.19
Olimex's FabGL version
ESP boards support 2.0.11 (chosen from the Boards manager in the IDE).

ESP boards support 2.0.17 may work too, which is the final version of 2.x.  3.x+ won't work - that's where I started, and that doesn't work either with the standard FabGL or Olimex's FabGL.

JacekRuzyczka, 2025-05-04:
OK, I've just checked out the "legacy" (= 1.8.19) version of the IDE, installed the board driver and Olimex's FabGL libs — and suddenly it compiles and runs! The question, which remains, is: Why does success depend on the IDE version?

And no, I installed the IDE from the packages supplied by Arduino.

**Last question:** Do I have to install a formatted SD card on the board, or is this "only" necessary for certain apps?

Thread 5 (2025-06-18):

AnsiTerminal: Two vttest tests have failed.

JacekRuzyczka, 2025-06-18:
I've just run parts of the `vttest` suite against the `AnsiTerminal` program. Two of them failed:

The test for ANSI colors revealed that the terminal can't display the color _blue_, neither the bright, nor the "normal" flavor.

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

The other test is called _character position absolute (HPA)_, which should display a box of asterisks, but the left and right edge of the box are depicted the wrong way:

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

Terminal type is ANSI.

DanKoloff, 2025-06-19:
When you first power the board what info does it say about "AnsiTerminal"? What are the first few lines displayed on the terminal?

DanKoloff, 2025-06-25:
My advice is to post in the FabGL repo asking for advice, Fabrizio and his community will know more why does this happen:

https://github.com/fdivitto/FabGL

I don't think this issue is due to the hardware. Maybe some configuration option or limitation is in place. We don't have much experience with the AnsiTerminal to give you good advice.

JacekRuzyczka, 2025-07-06:
OK, I posted this issue at FabGL, but haven't got a response from Fabrizio.

Is it true that the ports of the CH32V003F4P6 expander are linked to the
UEXT connector?

Am Mi., 25. Juni 2025 um 07:31 Uhr schrieb DanKoloff <
***@***.***>:

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

DanKoloff, 2025-07-21:
From what I see not all demos were edited and tested, no. Only "[HardwareTest](https://github.com/OLIMEX/FabGL/tree/master/examples/VGA/HardwareTest)", "[PCEmulator](https://github.com/OLIMEX/FabGL/tree/master/examples/VGA/PCEmulator)", "[SpaceInvaders](https://github.com/OLIMEX/FabGL/tree/master/examples/VGA/SpaceInvaders)". These three can be used as template to what has to be done.

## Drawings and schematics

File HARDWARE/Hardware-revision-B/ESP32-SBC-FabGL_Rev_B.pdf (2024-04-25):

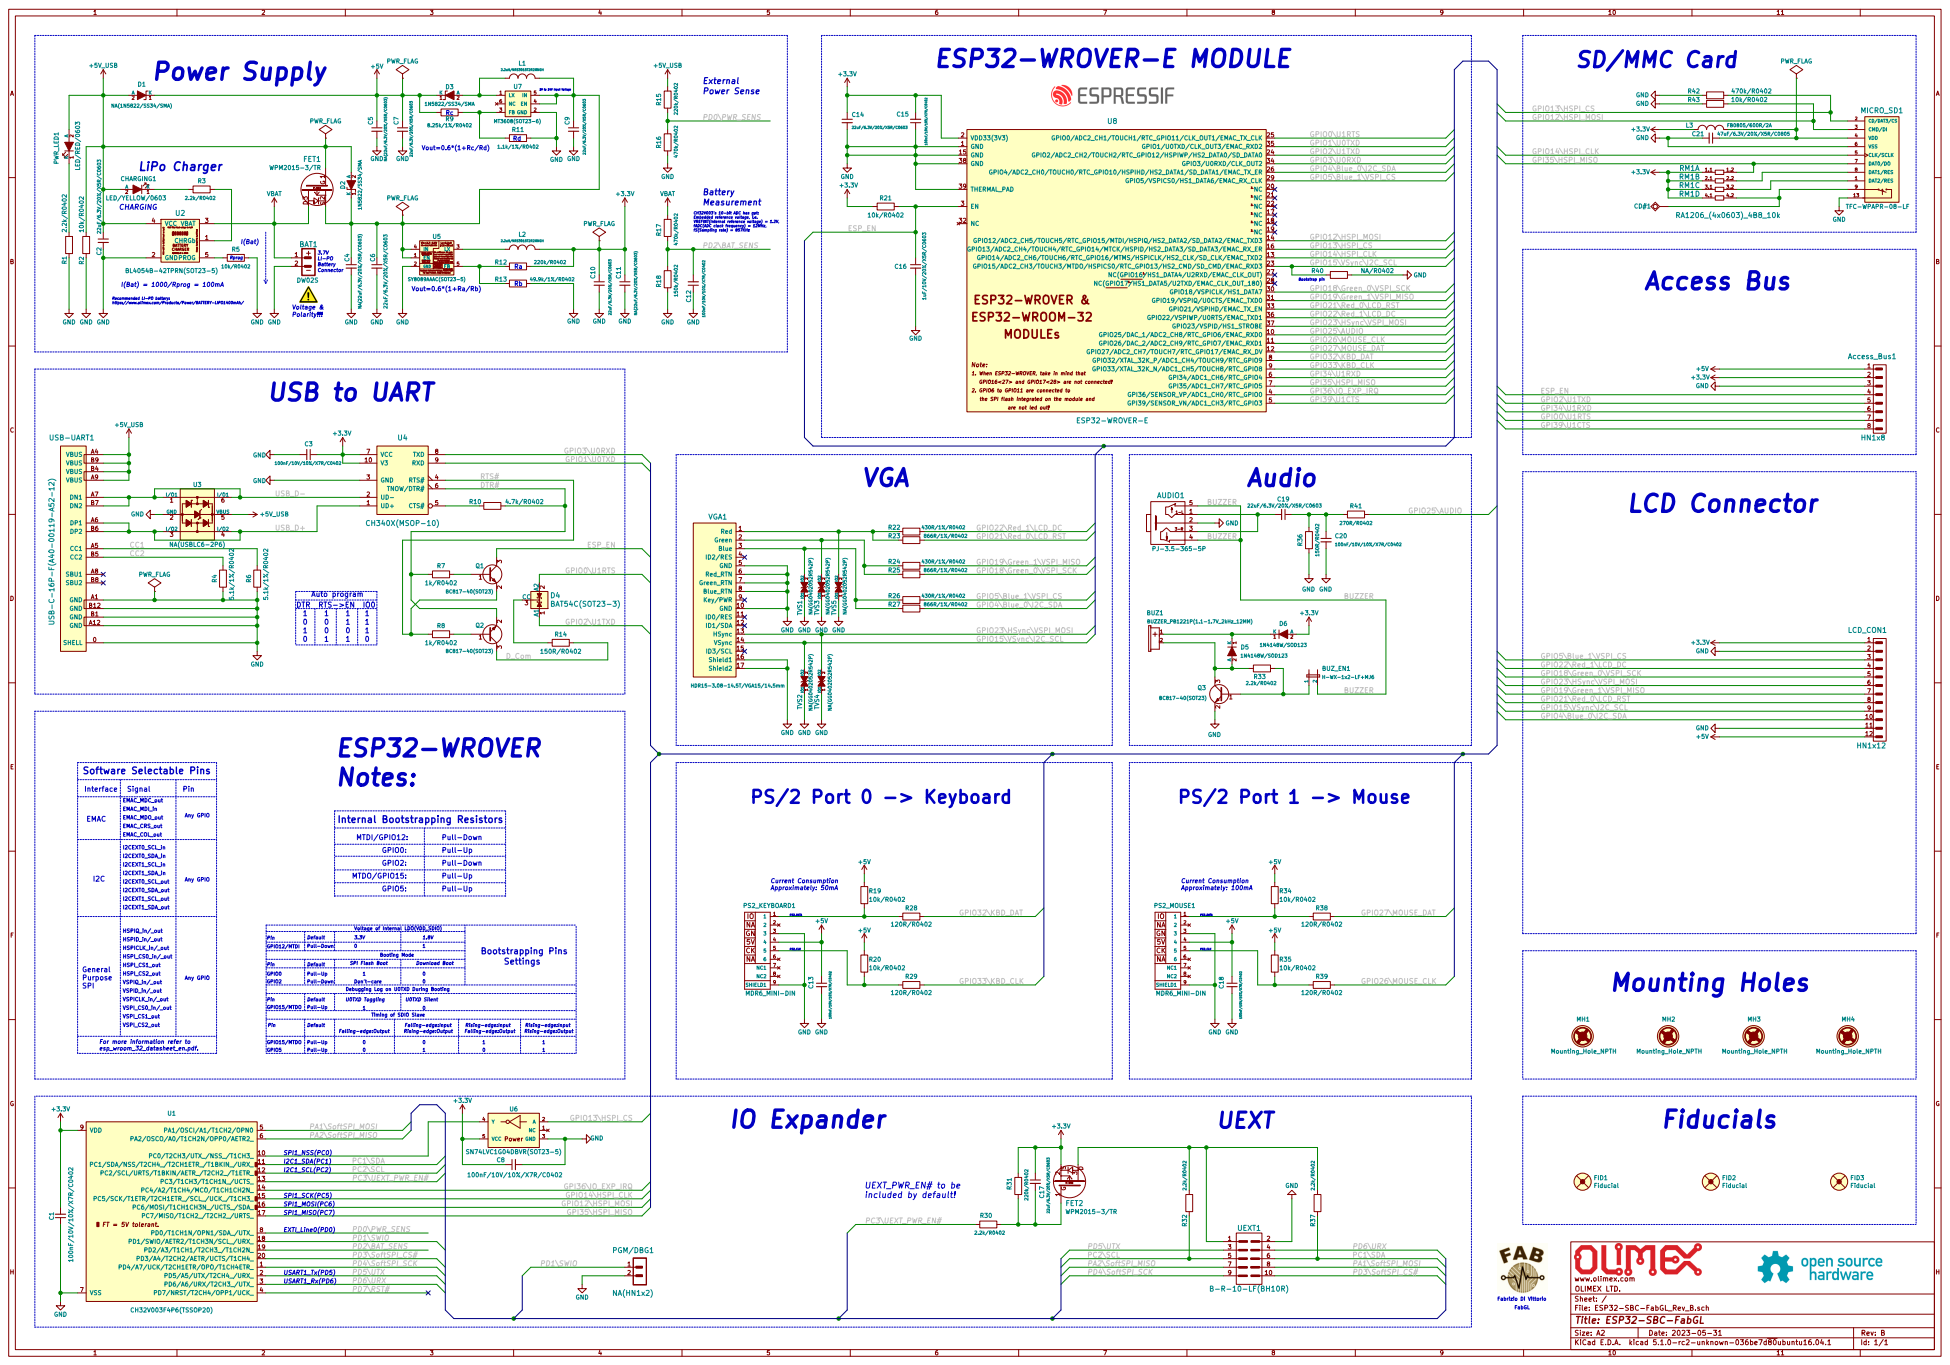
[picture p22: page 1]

TFC-WPAPR-08-LF GND

2 FET1 WPM2015-3/TR GND Charge Current Up to 800mA R(PROG)=2 to 10k VBAT final float voltage to 4.2V VCC=4.5V to 6.5V(at least a 1 F) BATTERY CHARGER CHRGb 1 GND 2 VBAT 3 VCC 4 PROG 5 U2

2. 2. 2. 2. 2. 2. 2. GPIO6 to GPIO11 are connected to are not led out! ESP32-WROOM-32

CH32V003's 10-bit ADC has got: Embedded reference voltage, i.e. VREFINT(Internal reference voltage) = 1.2V,

fADC(ADC clock frequency) = 12MHz,

load current capability! Lx=2.2uH

Vout=0.6*(1+Ra/Rb) EN 1 GND 2

Do not float. Enable control. FB Input Current, I(FB)=50nA(max) Feedback Reference Voltage, V(REF)=0.6V

GPIO16<27> and GPIO17<28> are not connected! MODULEs

22uF/6.3V/20%/X5R/C0603 GND GND GND BUZZER

2 BUZ_EN1 H-WX-1x2-LF+MJ6 GND IO11 IO22 TVS4 NA(GG0402052R542P) GND IO11 IO22 TVS2 NA(GG0402052R542P) GND

EMAC_COL_out Interface EMAC EMAC_MDC_out EMAC_MDI_in EMAC_MDO_out EMAC_CRS_out | Any GPIO

Signal | Pin

I2CEXT0_SCL_in I2CEXT0_SDA_in I2CEXT1_SCL_in I2CEXT1_SDA_in I2CEXT0_SCL_out I2CEXT0_SDA_out I2CEXT1_SCL_out

I2CEXT1_SDA_out HSPIQ_in/_out HSPID_in/_out HSPICLK_in/_out HSPI_CS0_in/_out HSPI_CS1_out HSPI_CS2_out VSPIQ_in/_out VSPID_in/_out VSPI_CS0_in/_out VSPICLK_in/_out VSPI_CS1_out VSPI_CS2_out | Any GPIO General Purpose SPI Any GPIO

Bootstrapping Pins Settings

GPIO2 | 0

1 Rising-edge:Input

File: ESP32-SBC-FabGL_Rev_B.sch Sheet: / OLIMEX LTD. www.olimex.com

Fabrizio Di Vittorio FabGL

Id: 1/1 Title: ESP32-SBC-FabGL

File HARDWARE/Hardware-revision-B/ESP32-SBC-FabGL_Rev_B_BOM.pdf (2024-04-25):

ESP32-SBC-FabGL_Rev_B_BOM | 07/13/2023

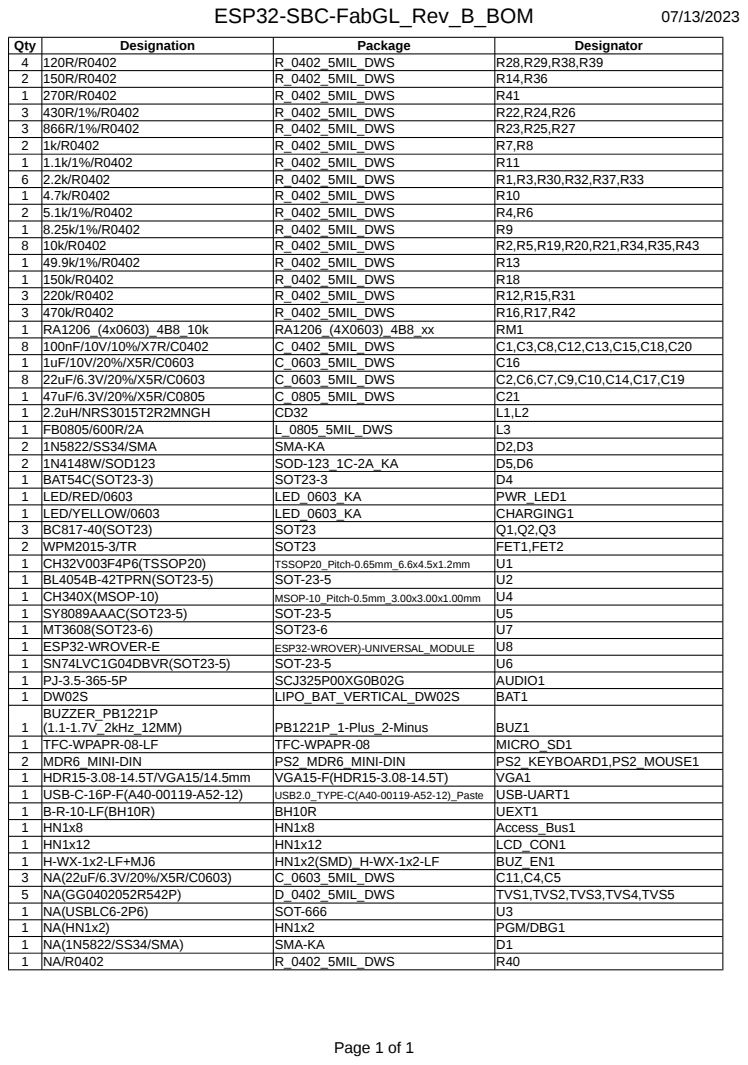
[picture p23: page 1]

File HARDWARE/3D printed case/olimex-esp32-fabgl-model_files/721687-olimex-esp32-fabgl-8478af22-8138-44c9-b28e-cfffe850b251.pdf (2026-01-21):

# Olimex ESP32

# FabGL

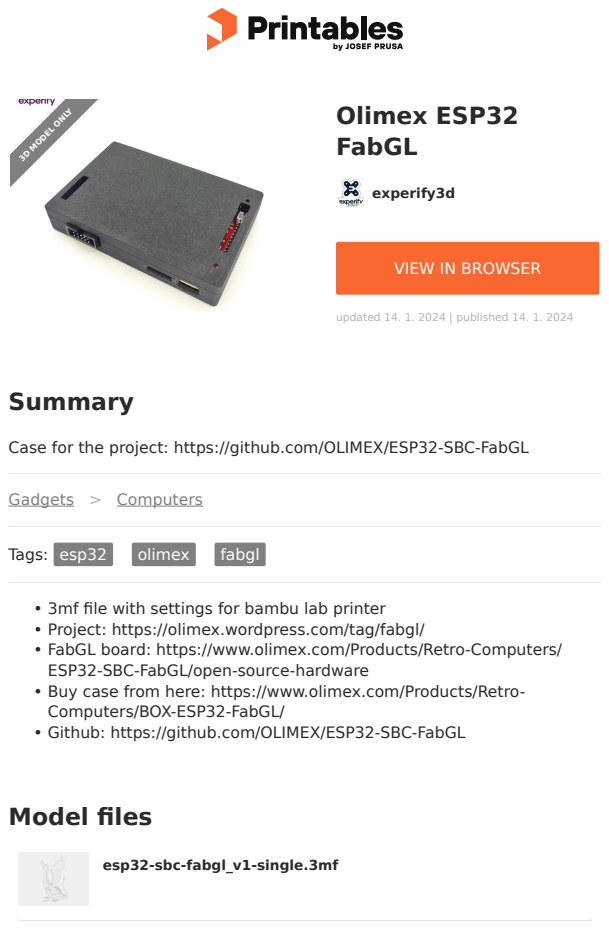
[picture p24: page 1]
Model files; Summary; Gadgets; Computers; Tags: esp32; olimex; fabgl; experify3d; updated 14. 1. 2024 | published 14. 1. 2024; esp32-sbc-fabgl_v1-single.3mf; 3D MODEL ONLY

VIEW IN BROWSER (https://printables.com/model/721687-olimex-esp32-fabgl)

Case for the project: https://github.com/OLIMEX/ESP32-SBC-FabGL

3mf file with settings for bambu lab printer
Project: https://olimex.wordpress.com/tag/fabgl/
FabGL board: https://www.olimex.com/Products/Retro-Computers/
ESP32-SBC-FabGL/open-source-hardware
Buy case from here: https://www.olimex.com/Products/Retro-
Computers/BOX-ESP32-FabGL/
Github: https://github.com/OLIMEX/ESP32-SBC-FabGL

# License

This work is licensed under a

Creative Commons (4.0 International License)

Attribution-NonCommercial (http://creativecommons.org/licenses/by-nc/4.0/)

✖ | Sharing without ATTRIBUTION
✔ | Remix Culture allowed
✖ | Commercial Use
✖ | Free Cultural Works
✖ | Meets Open Definition

esp32-sbc-fabgl_v1-top.stl

esp32-sbc-fabgl_v1-bottom.stl

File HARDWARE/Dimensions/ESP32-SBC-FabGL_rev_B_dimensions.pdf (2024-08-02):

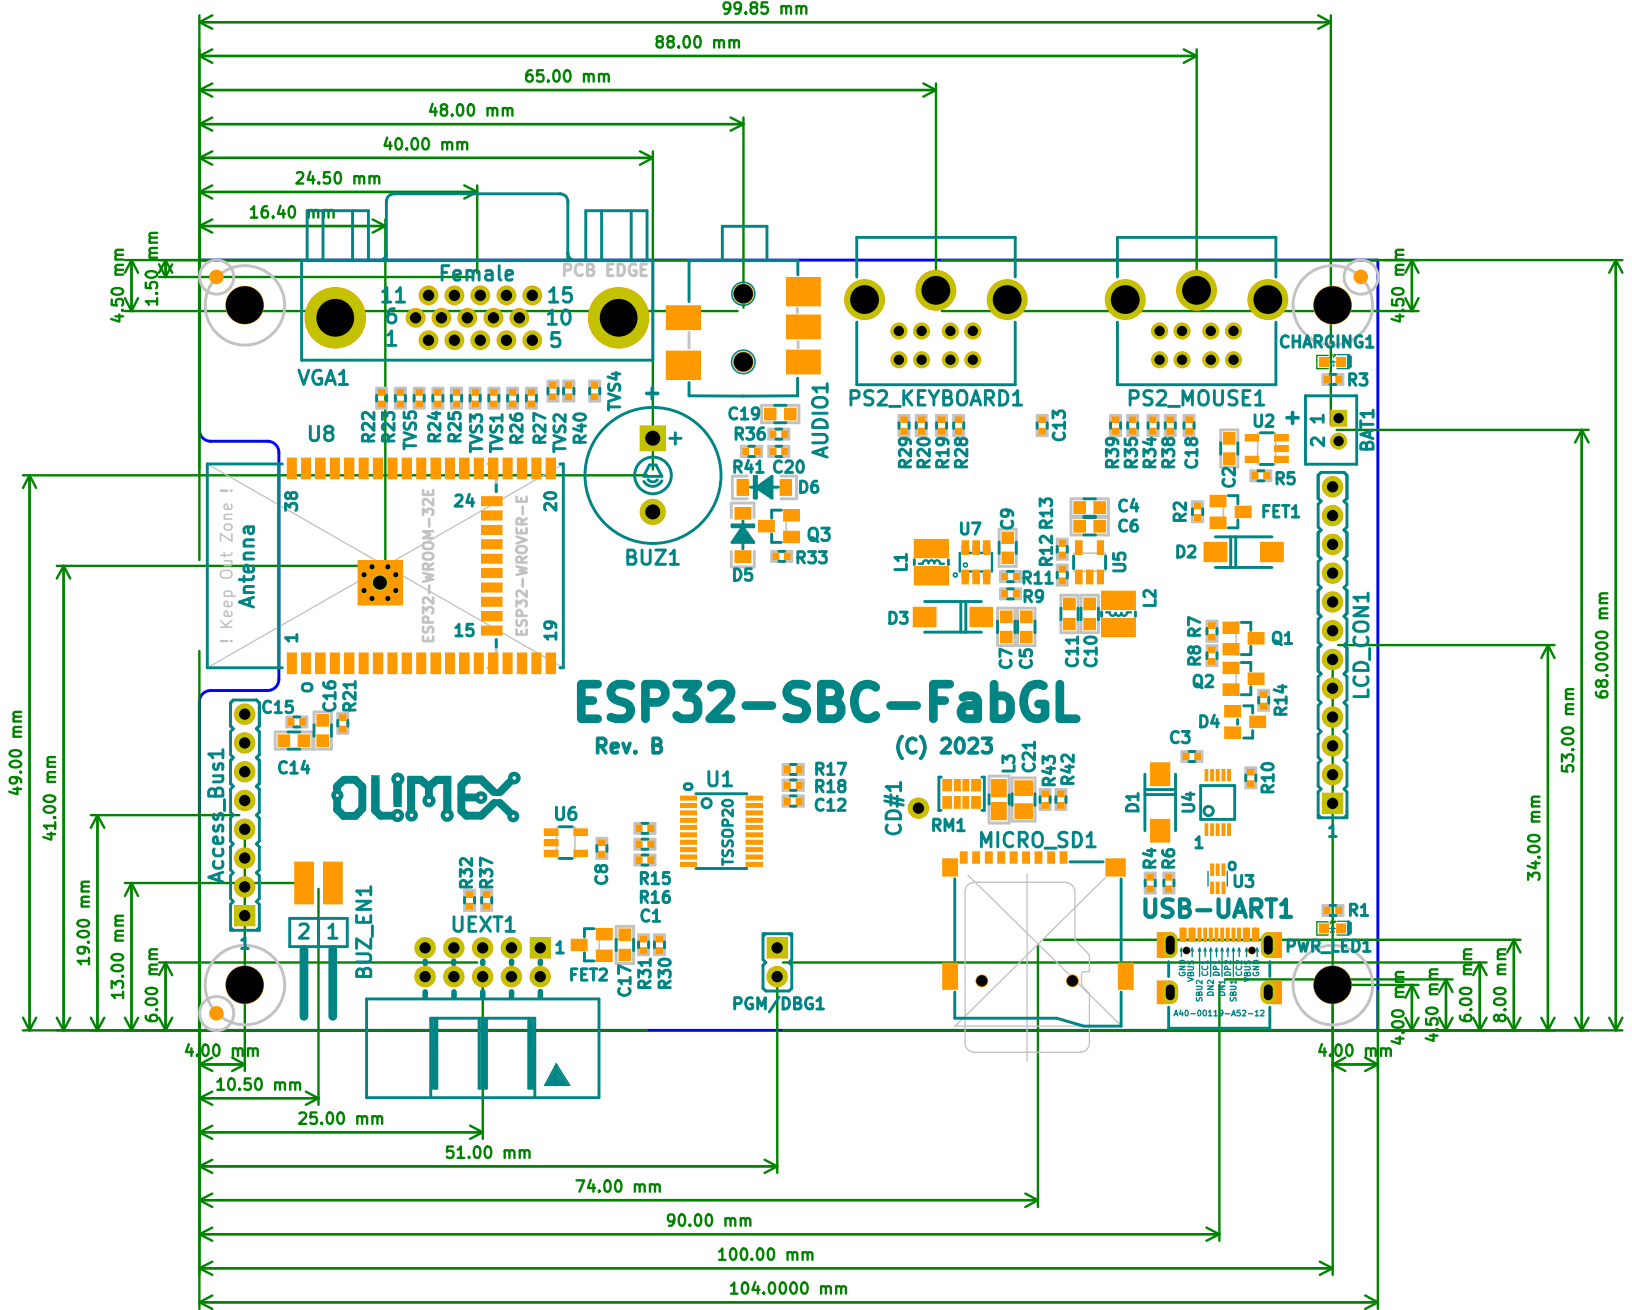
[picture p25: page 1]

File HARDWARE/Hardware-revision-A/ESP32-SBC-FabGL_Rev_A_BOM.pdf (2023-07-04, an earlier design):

ESP32-SBC-FabGL_Rev_A_BOM | 05/08/2023

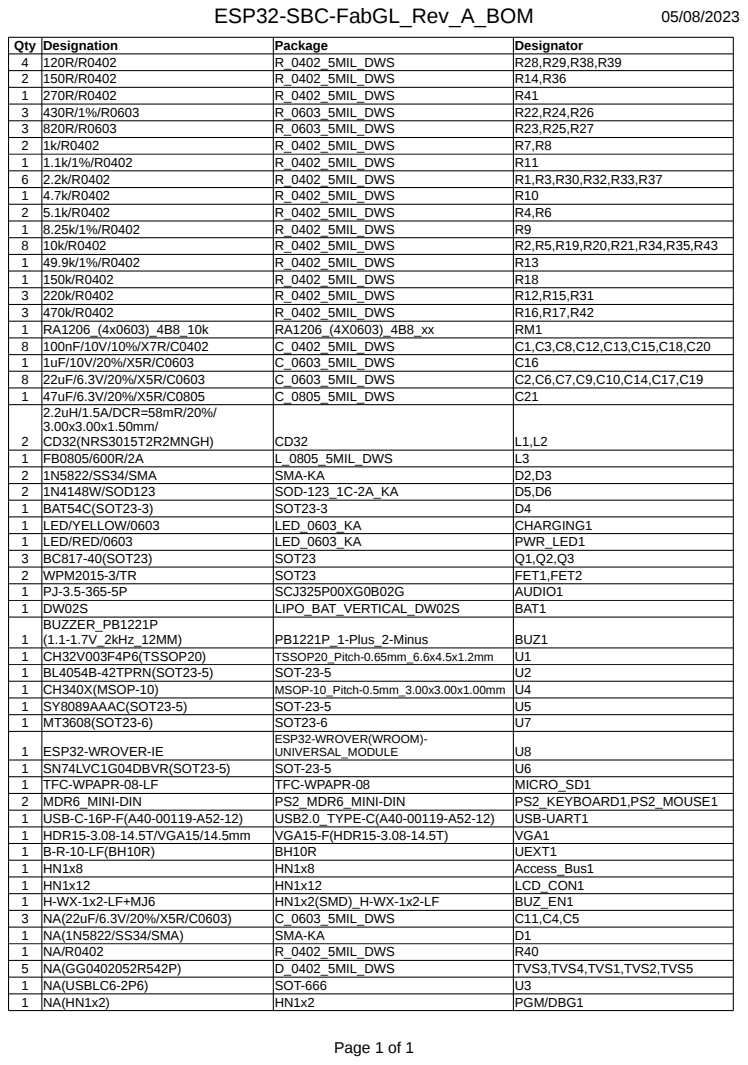
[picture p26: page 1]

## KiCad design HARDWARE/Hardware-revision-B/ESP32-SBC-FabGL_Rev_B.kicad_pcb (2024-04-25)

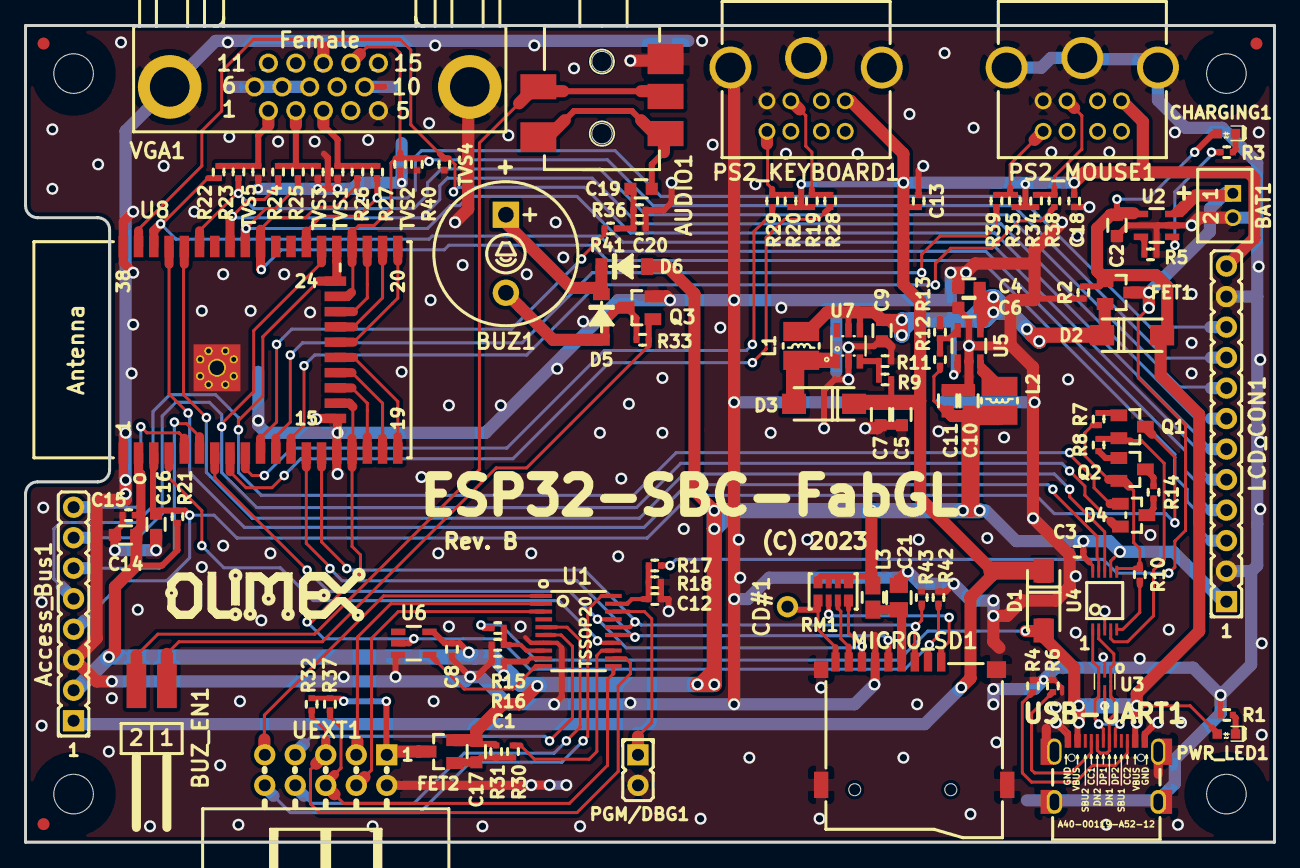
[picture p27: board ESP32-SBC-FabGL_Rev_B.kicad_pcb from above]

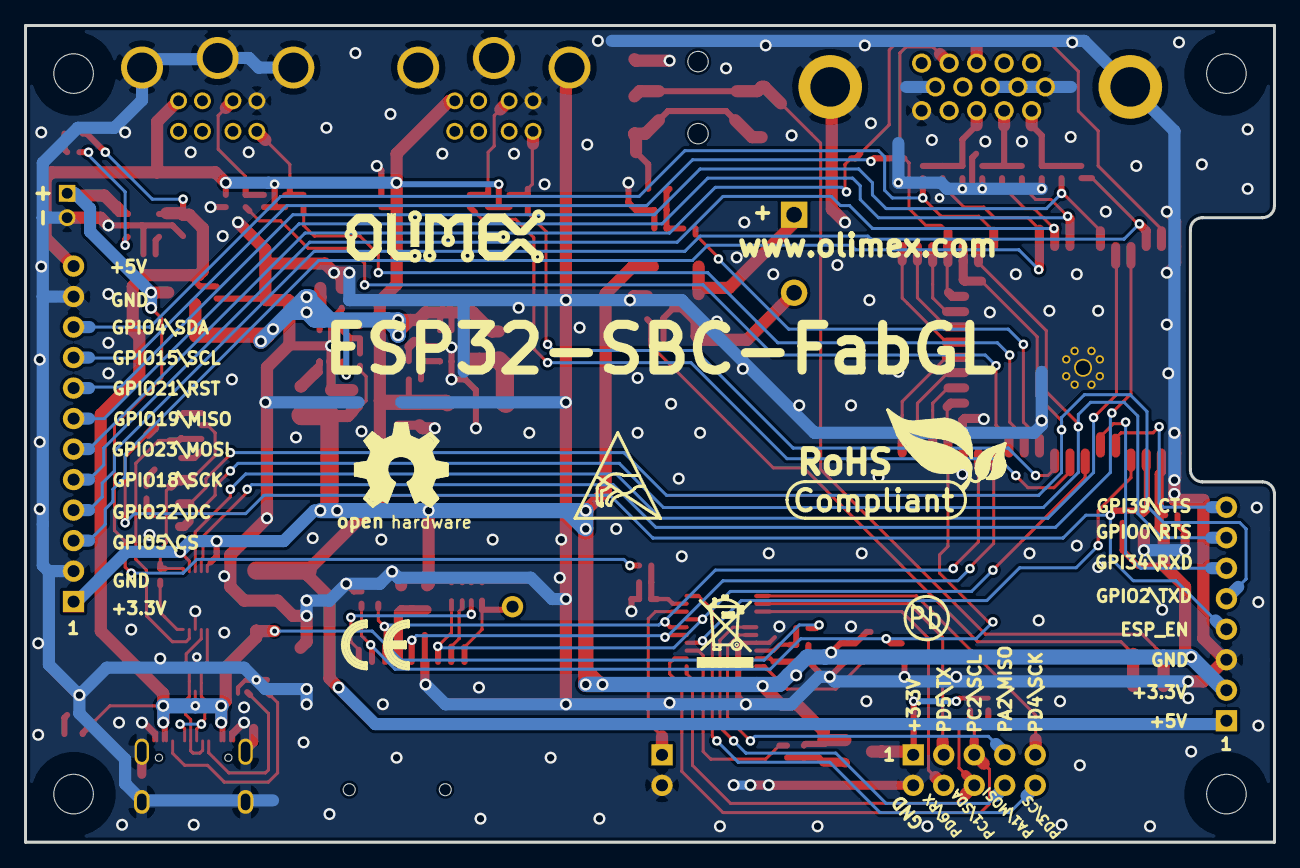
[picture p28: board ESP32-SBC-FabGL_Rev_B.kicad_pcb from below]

Board: 2 copper layers, 104.0 x 68.0 mm, 123 parts (7 on the bottom side), 82 nets.

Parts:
AUDIO1: PJ-3.5-365-5P; SCJ325P00XG0B02G
Access_Bus1: HN1x8
BAT1: DW02S; LIPO_BAT_VERTICAL_DW02S
BUZ1: BUZZER_PB1221P(1.1-1.7V_2kHz_12MM); PB1221P_1-Plus_2-Minus
BUZ_EN1: H-WX-1x2-LF+MJ6; HN1x2(SMD)_H-WX-1x2-LF
C1, C3, C8, C12, C13, C15, C18, C20: 100nF/10V/10%/X7R/C0402; C_0402_5MIL_DWS
C2, C6, C7, C9, C10, C14, C17, C19: 22uF/6.3V/20%/X5R/C0603; C_0603_5MIL_DWS
C4, C5, C11: NA(22uF/6.3V/20%/X5R/C0603); C_0603_5MIL_DWS
C16: 1uF/10V/20%/X5R/C0603; C_0603_5MIL_DWS
C21: 47uF/6.3V/20%/X5R/C0805; C_0805_5MIL_DWS
CD#1: TESTPAD; TEST_PAD_40x70_Round
CHARGING1: LED/YELLOW/0603; LED_0603_KA
D1: NA(1N5822/SS34/SMA); SMA-KA
D2, D3: 1N5822/SS34/SMA; SMA-KA
D4: BAT54C(SOT23-3); SOT23-3
D5, D6: 1N4148W/SOD123; SOD-123_1C-2A_KA
FET1, FET2: WPM2015-3/TR; SOT23
FID1, FID2, FID3: Fiducial; Fiducial1x3
L1, L2: 2.2uH/NRS3015T2R2MNGH; CD32
L3: FB0805/600R/2A; L_0805_5MIL_DWS
LCD_CON1: HN1x12
Logo_OLIMEX_TB-Bottom: Logo_OLIMEX_TB
Logo_OLIMEX_TB-Top: Logo_OLIMEX_TB
MH1, MH2, MH3, MH4: Mounting_Hole_NPTH; Mounting_Hole_Drill-3.3mm_Clerance-7mm
MICRO_SD1: TFC-WPAPR-08-LF; TFC-WPAPR-08
PGM/DBG1: NA(HN1x2); HN1x2
PS2_KEYBOARD1, PS2_MOUSE1: MDR6_MINI-DIN; PS2_MDR6_MINI-DIN
PWR_LED1: LED/RED/0603; LED_0603_KA
Q1, Q2, Q3: BC817-40(SOT23); SOT23
R1, R3, R30, R32, R33, R37: 2.2k/R0402; R_0402_5MIL_DWS
R2, R5, R19, R20, R21, R34, R35, R43: 10k/R0402; R_0402_5MIL_DWS
R4, R6: 5.1k/1%/R0402; R_0402_5MIL_DWS
R7, R8: 1k/R0402; R_0402_5MIL_DWS
R9: 8.25k/1%/R0402; R_0402_5MIL_DWS
R10: 4.7k/R0402; R_0402_5MIL_DWS
R11: 1.1k/1%/R0402; R_0402_5MIL_DWS
R12, R15, R31: 220k/R0402; R_0402_5MIL_DWS
R13: 49.9k/1%/R0402; R_0402_5MIL_DWS
R14, R36: 150R/R0402; R_0402_5MIL_DWS
R16, R17, R42: 470k/R0402; R_0402_5MIL_DWS
R18: 150k/R0402; R_0402_5MIL_DWS
R22, R24, R26: 430R/1%/R0402; R_0402_5MIL_DWS
R23, R25, R27: 866R/1%/R0402; R_0402_5MIL_DWS
R28, R29, R38, R39: 120R/R0402; R_0402_5MIL_DWS
R40: NA/R0402; R_0402_5MIL_DWS
R41: 270R/R0402; R_0402_5MIL_DWS
RM1: RA1206_(4x0603)_4B8_10k; RA1206_(4X0603)_4B8_xx
Sign_Antistatic: Sign_Antistatic
Sign_CE: CE_Sign
Sign_OSHW_8x8: Sign_OSHW_8x8
Sign_PB-Free: Sign_PB-Free
Sign_RecycleBin: Sign_RecycleBin; Sign_RecycleBin_1
Sign_RoHS: Sign_RoHS; Sign_RoHS_1
TVS1, TVS2, TVS3, TVS4, TVS5: NA(GG0402052R542P); D_0402_5MIL_DWS
U1: CH32V003F4P6(TSSOP20); TSSOP20_Pitch-0.65mm_6.6x4.5x1.2mm
U2: BL4054B-42TPRN(SOT23-5); SOT-23-5
U3: NA(USBLC6-2P6); SOT-666
U4: CH340X(MSOP-10); MSOP-10_Pitch-0.5mm_3.00x3.00x1.00mm
U5: SY8089AAAC(SOT23-5); SOT-23-5
U6: SN74LVC1G04DBVR(SOT23-5); SOT-23-5
U7: MT3608(SOT23-6); SOT23-6
U8: ESP32-WROVER-E; ESP32-WROVER(WROOM)-UNIVERSAL_MODULE
UEXT1: B-R-10-LF(BH10R); BH10R
USB-UART1: USB-C-16P-F(A40-00119-A52-12); USB2.0_TYPE-C(A40-00119-A52-12)_Paste
VGA1: HDR15-3.08-14.5T/VGA15/14.5mm; VGA15-F(HDR15-3.08-14.5T)

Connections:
+3.3V: Access_Bus1.2, C1.2, C3.1, C8.1, C10.1, C11.1, C14.1, C15.2, C17.1, D6.2, FET2.2, L2.2, L3.1, LCD_CON1.1, R12.2, R21.1, R31.1, RM1.1.1, RM1.2.1, RM1.3.1, RM1.4.1, U1.9, U4.7, U4.10, U6.5, U8.2
+5V: Access_Bus1.1, C5.1, C7.1, C13.1, C18.1, D1.1, D3.1, LCD_CON1.12, PS2_KEYBOARD1.4, PS2_MOUSE1.4, R9.1, R19.1, R20.1, R34.1, R35.1
+5V_USB: C2.1, CHARGING1.2, D1.2, D2.2, FET1.1, PWR_LED1.2, R2.1, R15.1, U2.4, U3.5, USB-UART1.A4, USB-UART1.A9, USB-UART1.B4, USB-UART1.B9
/BUZZER: AUDIO1.4, AUDIO1.5, BUZ_EN1.2
/CC1: R6.2, USB-UART1.A5
/CC2: R4.2, USB-UART1.B5
/DTR#: Q2.2, R7.1, R10.2, U4.6
/D_Com: Q2.3, R14.2
/ESP_EN: Access_Bus1.4, C16.1, Q1.3, R21.2, U8.3
/GPI34\U1RXD: Access_Bus1.6, U8.6
/GPI35\HSPI_MISO: MICRO_SD1.7, RM1.1.2, U1.17, U8.7
/GPI36\IO_EXP_IRQ: U1.14, U8.4
/GPI39\U1CTS: Access_Bus1.8, U8.5
/GPIO0\U1RTS: Access_Bus1.7, D4.2, U8.25
/GPIO1\U0TXD: U4.9, U8.35
/GPIO2\U1TXD: Access_Bus1.5, D4.1, U8.24
/GPIO3\U0RXD: U4.8, U8.34
/GPIO4\Blue_0\I2C_SDA: LCD_CON1.10, R27.2, U8.26
/GPIO5\Blue_1\VSPI_CS: LCD_CON1.3, R26.2, U8.29
/GPIO12\HSPI_MOSI: MICRO_SD1.3, R43.2, U1.16, U8.14
/GPIO13\HSPI_CS: MICRO_SD1.2, R42.2, U6.2, U8.16
/GPIO14\HSPI_CLK: MICRO_SD1.5, U1.15, U8.13
/GPIO15\VSync\I2C_SCL: LCD_CON1.9, R40.1, TVS2.2, U8.23, VGA1.14
/GPIO18\Green_0\VSPI_SCK: LCD_CON1.5, R25.2, U8.30
/GPIO19\Green_1\VSPI_MISO: LCD_CON1.7, R24.2, U8.31
/GPIO21\Red_0\LCD_RST: LCD_CON1.8, R23.2, U8.33
/GPIO22\Red_1\LCD_DC: LCD_CON1.4, R22.2, U8.36
/GPIO23\HSync\VSPI_MOSI: LCD_CON1.6, TVS4.2, U8.37, VGA1.13
/GPIO25\AUDIO: R41.2, U8.10
/GPIO26\MOUSE_CLK: R39.2, U8.11
/GPIO27\MOUSE_DAT: R38.2, U8.12
/GPIO32\KBD_DAT: R28.2, U8.8
/GPIO33\KBD_CLK: R29.2, U8.9
/PA1\SoftSPI_MOSI: U1.5, UEXT1.8
/PA2\SoftSPI_MISO: U1.6, UEXT1.7
/PC1\SDA: R37.2, U1.11, UEXT1.6
/PC2\SCL: R32.2, U1.12, UEXT1.5
/PC3\UEXT_PWR_EN#: R30.2, U1.13
/PD0\PWR_SENS: R15.2, R16.1, U1.8
/PD1\SWIO: PGM/DBG1.1, U1.18
/PD2\BAT_SENS: C12.2, R17.2, R18.1, U1.19
/PD3\SoftSPI_CS#: U1.20, UEXT1.10
/PD4\SoftSPI_SCK: U1.1, UEXT1.9
/PD5\UTX: U1.2, UEXT1.3
/PD6\URX: U1.3, UEXT1.4
/RTS#: Q1.2, R8.1, U4.4
/USB_D+: U3.3, U3.4, U4.1, USB-UART1.A6, USB-UART1.B6
/USB_D-: U3.1, U3.6, U4.2, USB-UART1.A7, USB-UART1.B7
GND: AUDIO1.2, Access_Bus1.3, BAT1.2, C1.1, C2.2, C3.2, C4.2, C5.2, C6.2, C7.2, C8.2, C9.2, C10.2, C11.2, C12.1, C13.2, C14.2, C15.1, C16.2, C18.2, C20.2, C21.2, LCD_CON1.2, LCD_CON1.11, MICRO_SD1.6, MICRO_SD1.10, MICRO_SD1.11, MICRO_SD1.12, MICRO_SD1.13, PGM/DBG1.2, PS2_KEYBOARD1.3, PS2_KEYBOARD1.9, PS2_MOUSE1.3, PS2_MOUSE1.9, Q3.2, R1.2, R2.2, R4.1, R5.2, R6.1, R11.2, R13.2, R16.2, R18.2, R36.2, R40.2, R42.1, R43.1, TVS1.1, TVS2.1, TVS3.1, TVS4.1, TVS5.1, U1.7, U2.2, U3.2, U4.3, U5.2, U6.3, U7.2, U8.1, U8.15, U8.38, U8.39, UEXT1.2, USB-UART1.0, USB-UART1.A1, USB-UART1.A12, USB-UART1.B1, USB-UART1.B12, VGA1.5, VGA1.6, VGA1.7, VGA1.8, VGA1.10, VGA1.16, VGA1.17
unnamed: AUDIO1.1, AUDIO1.3, C19.2
unnamed: BUZ1.1, D5.1, D6.1
unnamed: BUZ1.2, D5.2, Q3.3, R33.2
unnamed: BUZ_EN1.1, Q3.1, R33.1
unnamed: C4.1, C6.1, C9.1, D2.1, FET1.2, L1.2, U5.1, U5.4, U7.4, U7.5
unnamed: C17.2, FET2.1, R30.1, R31.2
unnamed: C19.1, C20.1, R36.1, R41.1
unnamed: C21.1, L3.2, MICRO_SD1.4
unnamed: CD#1.1, MICRO_SD1.9, RM1.4.2
unnamed: CHARGING1.1, R3.1
unnamed: D3.2, L1.1, U7.1
unnamed: D4.3, R14.1
unnamed: FET2.3, R32.1, R37.1, UEXT1.1
unnamed: L2.1, U5.3
unnamed: MICRO_SD1.1, RM1.3.2
unnamed: MICRO_SD1.8, RM1.2.2
unnamed: PS2_KEYBOARD1.1, R19.2, R28.1
unnamed: PS2_KEYBOARD1.5, R20.2, R29.1
unnamed: PS2_MOUSE1.1, R34.2, R38.1
unnamed: PS2_MOUSE1.5, R35.2, R39.1
unnamed: PWR_LED1.1, R1.1
unnamed: Q1.1, R7.2
unnamed: Q2.1, R8.2
unnamed: R3.2, U2.1
unnamed: R5.1, U2.5
unnamed: R10.1, U4.5
unnamed: R9.2, R11.1, U7.3
unnamed: R12.1, R13.1, U5.5
unnamed: R22.1, R23.1, TVS5.2, VGA1.1
unnamed: R24.1, R25.1, TVS3.2, VGA1.2
unnamed: R26.1, R27.1, TVS1.2, VGA1.3
unnamed: U1.10, U6.4
VBAT: BAT1.1, FET1.3, R17.1, U2.3

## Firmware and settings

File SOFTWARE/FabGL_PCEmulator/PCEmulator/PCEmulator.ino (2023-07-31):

/*
  Created by Fabrizio Di Vittorio (fdivitto2013@gmail.com) - <http://www.fabgl.com>
  Copyright (c) 2019-2022 Fabrizio Di Vittorio.
  All rights reserved.


* Please contact fdivitto2013@gmail.com if you need a commercial license.


* This library and related software is available under GPL v3.

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
  You should have received a copy of the GNU General Public License
  along with FabGL.  If not, see <http://www.gnu.org/licenses/>.
 */


 /* Instructions:

    - to run this application you need an ESP32 with PSRAM installed and an SD-CARD slot (ie TTGO VGA32 v1.4 or FabGL Development Board with WROVER)
    - open this with Arduino and make sure PSRAM is DISABLED
    - partition scheme must be: Huge App
    - compile and upload the sketch

 */


#pragma message "This sketch requires Tools->Partition Scheme = Huge APP"


#include <memory>

#include "esp32-hal-psram.h"
extern "C" {
#include "esp_spiram.h"
}
#include "esp_sntp.h"

#include <Preferences.h>
#include <WiFi.h>
#include <HTTPClient.h>

#include "fabgl.h"

#include "mconf.h"
#include "machine.h"



// UART Pins for USB serial
#define UART_URX 3
#define UART_UTX 1



using std::unique_ptr;

using fabgl::StringList;
using fabgl::imin;
using fabgl::imax;



Preferences   preferences;
InputBox      ibox;
Machine     * machine;


// noinit! Used to maintain datetime between reboots
__NOINIT_ATTR static timeval savedTimeValue;


static bool wifiConnected = false;
static bool downloadOK    = false;


// try to connected using saved parameters
bool tryToConnect()
{
  bool connected = WiFi.status() == WL_CONNECTED;
  if (!connected) {
    char SSID[32] = "";
    char psw[32]  = "";
    if (preferences.getString("SSID", SSID, sizeof(SSID)) && preferences.getString("WiFiPsw", psw, sizeof(psw))) {
      ibox.progressBox("", "Abort", true, 200, [&](fabgl::ProgressForm * form) {
        WiFi.begin(SSID, psw);
        for (int i = 0; i < 32 && WiFi.status() != WL_CONNECTED; ++i) {
          if (!form->update(i * 100 / 32, "Connecting to %s...", SSID))
            break;
          delay(500);
          if (i == 16)
            WiFi.reconnect();
        }
        connected = (WiFi.status() == WL_CONNECTED);
      });
      // show to user the connection state
      if (!connected) {
        WiFi.disconnect();
        ibox.message("", "WiFi Connection failed!");
      }
    }
  }
  return connected;
}


bool checkWiFi()
{
  wifiConnected = tryToConnect();
  if (!wifiConnected) {

    // configure WiFi?
    if (ibox.message("WiFi Configuration", "Configure WiFi?", "No", "Yes") == InputResult::Enter) {

      // repeat until connected or until user cancels
      do {

        // yes, scan for networks showing a progress dialog box
        int networksCount = 0;
        ibox.progressBox("", nullptr, false, 200, [&](fabgl::ProgressForm * form) {
          form->update(0, "Scanning WiFi networks...");
          networksCount = WiFi.scanNetworks();
        });

        // are there available WiFi?
        if (networksCount > 0) {

          // yes, show a selectable list
          StringList list;
          for (int i = 0; i < networksCount; ++i)
            list.appendFmt("%s (%d dBm)", WiFi.SSID(i).c_str(), WiFi.RSSI(i));
          int s = ibox.menu("WiFi Configuration", "Please select a WiFi network", &list);

          // user selected something?
          if (s > -1) {
            // yes, ask for WiFi password
            char psw[32] = "";
            if (ibox.textInput("WiFi Configuration", "Insert WiFi password", psw, 31, "Cancel", "OK", true) == InputResult::Enter) {
              // user pressed OK, connect to WiFi...
              preferences.putString("SSID", WiFi.SSID(s).c_str());
              preferences.putString("WiFiPsw", psw);
              wifiConnected = tryToConnect();
              // show to user the connection state
              if (wifiConnected)
                ibox.message("", "Connection succeeded!");
            } else
              break;
          } else
            break;
        } else {
          // there is no WiFi
          ibox.message("", "No WiFi network found!");
          break;
        }
        WiFi.scanDelete();

      } while (!wifiConnected);

    }

  }

  return wifiConnected;
}


// handle soft restart
void shutdownHandler()
{
  // save current datetime into Preferences
  gettimeofday(&savedTimeValue, nullptr);
}


void updateDateTime()
{
  // Set timezone
  setenv("TZ", "CET-1CEST,M3.5.0,M10.5.0/3", 1);
  tzset();

  // get datetime from savedTimeValue? (noinit section)
  if (esp_reset_reason() == ESP_RST_SW) {
    // adjust time taking account elapsed time since ESP32 started
    savedTimeValue.tv_usec += (int) esp_timer_get_time();
    savedTimeValue.tv_sec  += savedTimeValue.tv_usec / 1000000;
    savedTimeValue.tv_usec %= 1000000;
    settimeofday(&savedTimeValue, nullptr);
    return;
  }

  if (checkWiFi()) {

    // we need time right now
    ibox.progressBox("", nullptr, true, 200, [&](fabgl::ProgressForm * form) {
      sntp_setoperatingmode(SNTP_OPMODE_POLL);
      sntp_setservername(0, (char*)"pool.ntp.org");
      sntp_init();
      for (int i = 0; i < 12 && sntp_get_sync_status() != SNTP_SYNC_STATUS_COMPLETED; ++i) {
        form->update(i * 100 / 12, "Getting date-time from SNTP...");
        delay(500);
      }
      sntp_stop();
      ibox.setAutoOK(2);
      ibox.message("", "Date and Time updated. Restarting...");
      #ifndef FABGL_EMULATED
      esp_restart();
      #endif
    });

  } else {

    // set default time
    auto tm = (struct tm){ .tm_sec  = 0, .tm_min  = 0, .tm_hour = 8, .tm_mday = 14, .tm_mon  = 7, .tm_year = 84 };
    auto now = (timeval){ .tv_sec = mktime(&tm) };
    settimeofday(&now, nullptr);

  }
}


// download specified filename from URL
bool downloadURL(char const * URL, FILE * file)
{
  downloadOK = false;

  char const * filename = strrchr(URL, '/') + 1;

  ibox.progressBox("", "Abort", true, 380, [&](fabgl::ProgressForm * form) {
    form->update(0, "Preparing to download %s", filename);
    HTTPClient http;
    http.setFollowRedirects(HTTPC_STRICT_FOLLOW_REDIRECTS);
    http.begin(URL);
    int httpCode = http.GET();
    if (httpCode == HTTP_CODE_OK) {
      if (file) {
        int tlen = http.getSize();
        int len = tlen;
        auto buf = (uint8_t*) SOC_EXTRAM_DATA_LOW; // use PSRAM as buffer
        WiFiClient * stream = http.getStreamPtr();
        int dsize = 0;
        while (http.connected() && (len > 0 || len == -1)) {
          size_t size = stream->available();
          if (size) {
            int c = stream->readBytes(buf, size);
            auto wr = fwrite(buf, 1, c, file);
            if (wr != c) {
              dsize = 0;
              break;  // writing failure!
            }
            dsize += c;
            if (len > 0)
              len -= c;
            if (!form->update((int64_t)dsize * 100 / tlen, "Downloading %s (%.2f / %.2f MB)", filename, (double)dsize / 1048576.0, tlen / 1048576.0))
              break;
          }
        }
        downloadOK = (len == 0 || (len == -1 && dsize > 0));
      }
    }
    http.end();
  });

  return downloadOK;
}


// return filename if successfully downloaded or already exist
char const * getDisk(char const * url)
{
  FileBrowser fb(SD_MOUNT_PATH);

  char const * filename = nullptr;
  if (url) {
    if (strncmp("http://", url, 7) == 0 || strncmp("https://", url, 7) == 0) {
      // this is actually an URL
      filename = strrchr(url, '/') + 1;
      if (filename && !fb.exists(filename, false)) {
        // disk doesn't exist, try to download
        if (!checkWiFi())
          return nullptr;
        auto file = fb.openFile(filename, "wb");
        bool success = downloadURL(url, file);
        fclose(file);
        if (!success) {
          fb.remove(filename);
          return nullptr;
        }
      }
    } else {
      // this is just a file
      if (fb.filePathExists(url))
        filename = url;
    }
  }
  return filename;
}


// user pressed SYSREQ (ALT + PRINTSCREEN)
void sysReqCallback()
{
  machine->graphicsAdapter()->enableVideo(false);
  ibox.begin(VGA_640x480_60Hz, 500, 400, 4);

  int s = ibox.menu("", "Select a command", "Restart Emulator;Restart Machine;Mount Disk;Continue");
  switch (s) {

    // Restart Emulator
    case 0:
      esp_restart();
      break;
      
    // Restart Machine
    case 1:
      machine->trigReset();
      break;

    // Mount Disk
    case 2:
    {
      int s = ibox.menu("", "Select Drive", "Floppy A (fd0);Floppy B (fd1)");
      if (s > -1) {
        constexpr int MAXNAMELEN = 256;
        unique_ptr<char[]> dir(new char[MAXNAMELEN + 1] { '/', 'S', 'D', 0 } );
        unique_ptr<char[]> filename(new char[MAXNAMELEN + 1] { 0 } );
        if (machine->diskFilename(s))
          strcpy(filename.get(), machine->diskFilename(s));
        if (ibox.fileSelector("Select Disk Image", "Image Filename", dir.get(), MAXNAMELEN, filename.get(), MAXNAMELEN) == InputResult::Enter) {
          machine->setDriveImage(s, filename.get());
        }
      }
      break;
    }

    // Continue
    default:
      break;
  }

  ibox.end();
  PS2Controller::keyboard()->enableVirtualKeys(false, false); // don't use virtual keys
  machine->graphicsAdapter()->enableVideo(true);
}


void setup()
{
  Serial.begin(115200); delay(500); printf("\n\n\nReset\n\n");// DEBUG ONLY


  disableCore0WDT();
  delay(100); // experienced crashes without this delay!
  disableCore1WDT();

  preferences.begin("PCEmulator", false);

  // uncomment to clear preferences
  //preferences.clear();
  
  // save some space reducing UI queue
  fabgl::BitmappedDisplayController::queueSize = 128;

  ibox.begin(VGA_640x480_60Hz, 500, 400, 4);
  ibox.setBackgroundColor(RGB888(0, 0, 0));

  ibox.onPaint = [&](Canvas * canvas) { drawInfo(canvas); };

  // we need PSRAM for this app, but we will handle it manually, so please DO NOT enable PSRAM on your development env
  #ifdef BOARD_HAS_PSRAM
  ibox.message("Warning!", "Please disable PSRAM to improve performance!");
  #endif

  // note: we use just 2MB of PSRAM so the infamous PSRAM bug should not happen. But to avoid gcc compiler hack (-mfix-esp32-psram-cache-issue)
  // we enable PSRAM at runtime, otherwise the hack slows down CPU too much (PSRAM_HACK is no more required).
  if (esp_spiram_init() != ESP_OK)
    ibox.message("Error!", "This app requires a board with PSRAM!", nullptr, nullptr);

  #ifndef BOARD_HAS_PSRAM
  esp_spiram_init_cache();
  #endif

  if (!FileBrowser::mountSDCard(false, SD_MOUNT_PATH, 8))   // @TODO: reduce to 4?
    ibox.message("Error!", "This app requires a SD-CARD!", nullptr, nullptr);

  // uncomment to format SD!
  //FileBrowser::format(fabgl::DriveType::SDCard, 0);

  esp_register_shutdown_handler(shutdownHandler);

  updateDateTime();

  // machine configurations
  MachineConf mconf;

  // show a list of machine configurations

  ibox.setAutoOK(6);
  int idx = preferences.getInt("dconf", 0);

  for (bool showDialog = true; showDialog; ) {

    loadMachineConfiguration(&mconf);

    StringList dconfs;
    for (auto conf = mconf.getFirstItem(); conf; conf = conf->next)
      dconfs.append(conf->desc);
    dconfs.select(idx, true);

    ibox.setupButton(0, "Files");
    ibox.setupButton(1, "Machine", "Edit;New;Remove", 52);
    auto r = ibox.select("Machine Configurations", "Please select a machine configuration", &dconfs, nullptr, "Run");

    idx = dconfs.getFirstSelected();

    switch (r) {
      case InputResult::ButtonExt0:
        // Browse Files
        ibox.folderBrowser("Browse Files", SD_MOUNT_PATH);
        break;
      case InputResult::ButtonExt1:
        // Machine
        switch (ibox.selectedSubItem()) {
          // Edit
          case 0:
            editConfigDialog(&ibox, &mconf, idx);
            break;
          // New
          case 1:
            newConfigDialog(&ibox, &mconf, idx);
            break;
          // Remove
          case 2:
            delConfigDialog(&ibox, &mconf, idx);
            break;
        };
        break;
      case InputResult::Enter:
        // Run
        showDialog = false;
        break;
      default:
        break;
    }

    // next selection will not have timeout
    ibox.setAutoOK(0);
  }

  idx = imax(idx, 0);
  preferences.putInt("dconf", idx);

  // setup selected configuration
  auto conf = mconf.getItem(idx);

  char const * diskFilename[DISKCOUNT];
  downloadOK = true;
  for (int i = 0; i < DISKCOUNT && downloadOK; ++i)
    diskFilename[i] = getDisk(conf->disk[i]);

  if (!downloadOK || (!diskFilename[0] && !diskFilename[2])) {
    // unable to get boot disks
    ibox.message("Error!", "Unable to get system disks!");
    esp_restart();
  }

  if (wifiConnected) {
    // disk downloaded from the Internet, need to reboot to fully disable wifi
    ibox.setAutoOK(2);
    ibox.message("", "Disks downloaded. Restarting...");
    #ifndef FABGL_EMULATED
    esp_restart();
    #endif
  }

  ibox.end();
  
  // without WiFi it is possible to increase SD card speed
  FileBrowser::setSDCardMaxFreqKHz(SDMMC_FREQ_DEFAULT);
  FileBrowser::remountSDCard();

  machine = new Machine;

  machine->setBaseDirectory(SD_MOUNT_PATH);
  for (int i = 0; i < DISKCOUNT; ++i)
    machine->setDriveImage(i, diskFilename[i], conf->cylinders[i], conf->heads[i], conf->sectors[i]);

  machine->setBootDrive(conf->bootDrive);
  
  auto serial1 = new SerialPort;
  serial1->setSignals(UART_URX, UART_UTX);
  machine->setCOM1(serial1);

  /*
  printf("MALLOC_CAP_32BIT : %d bytes (largest %d bytes)\r\n", heap_caps_get_free_size(MALLOC_CAP_32BIT), heap_caps_get_largest_free_block(MALLOC_CAP_32BIT));
  printf("MALLOC_CAP_8BIT  : %d bytes (largest %d bytes)\r\n", heap_caps_get_free_size(MALLOC_CAP_8BIT), heap_caps_get_largest_free_block(MALLOC_CAP_8BIT));
  printf("MALLOC_CAP_DMA   : %d bytes (largest %d bytes)\r\n\n", heap_caps_get_free_size(MALLOC_CAP_DMA), heap_caps_get_largest_free_block(MALLOC_CAP_DMA));

  heap_caps_dump_all();
  */

  machine->setSysReqCallback(sysReqCallback);
  
  machine->run();
}



#if FABGLIB_VGAXCONTROLLER_PERFORMANCE_CHECK
namespace fabgl {
  extern volatile uint64_t s_vgapalctrlcycles;
}
using fabgl::s_vgapalctrlcycles;
#endif



void loop()
{

#if FABGLIB_VGAXCONTROLLER_PERFORMANCE_CHECK
  static uint32_t tcpu = 0, s1 = 0, count = 0;
  tcpu = machine->ticksCounter();
  s_vgapalctrlcycles = 0;
  s1 = fabgl::getCycleCount();
  delay(1000);
  printf("%d\tCPU: %d", count, machine->ticksCounter() - tcpu);
  printf("   Graph: %lld / %d   (%d%%)\n", s_vgapalctrlcycles, fabgl::getCycleCount() - s1, (int)((double)s_vgapalctrlcycles/240000000*100));
  ++count;
#else

  vTaskDelete(NULL);

#endif
}

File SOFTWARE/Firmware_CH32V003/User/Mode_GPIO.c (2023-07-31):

#include "Mode_GPIO.h"
#include "Uptime.h"

#undef _DEBUG_
#ifdef DEBUG_MODE_GPIO
#define _DEBUG_ 1
#else
#define _DEBUG_ 0
#endif

//                                              PA    PB    PC    PD
static uint8_t GPIO_Available_Pins[5] = {0x00, 0x06, 0x00, 0x1E, 0x7D};

//                                      PA    PB    PC    PD
static uint8_t INT_Flags[5]   = {0x00, 0x00, 0x00, 0x00, 0x00};
static uint8_t INT_Capture[5] = {0x00, 0x00, 0x00, 0x00, 0x00};

static uint8_t INT_Level = 1;
static uint8_t in_interrupt = 0;

GPIO_Error_Type IndexToPort (GPIO_PORT_Index GPIO_Port, GPIO_TypeDef* *GPIO)
{
    switch (GPIO_Port)
    {
        case GPIO_PORTA:
            *GPIO = GPIOA;
        break;
        case GPIO_PORTC:
            *GPIO = GPIOC;
        break;
        case GPIO_PORTD:
            *GPIO = GPIOD;
        break;
        default:
            *GPIO = NULL;
            return GPIO_ERROR;
        break;
    }
    return GPIO_SUCCESS;
}

static uint32_t EXTI_Get_Line_Port(uint32_t EXTI_LineX)
{
    uint32_t mask = ((uint32_t)(3 << (EXTI_LineX << 1)));
    return ((AFIO->EXTICR & mask) >> (EXTI_LineX << 1)) + 1;
}

static void Interrupt_Set_Output()
{
    for (uint8_t i=1; i<5; i++)
        if (INT_Flags[i]) {
            Port_Set_Output (IO_EXP_IRQ_PORT, IO_EXP_IRQ_PIN, INT_Level ? IO_EXP_IRQ_PIN : 0x00);
            return;
        }
    Port_Set_Output (IO_EXP_IRQ_PORT, IO_EXP_IRQ_PIN, INT_Level ? 0x00 : IO_EXP_IRQ_PIN);
}

// ----------------------------------------------------------- GPIO ---------------------------------------------------------------------------

GPIO_Error_Type Port_Configuration (GPIO_PORT_Index GPIO_Port, uint16_t GPIO_Pins, uint16_t GPIO_Directions, uint16_t GPIO_PullUp)
{
    GPIO_TypeDef* GPIO;
    uint32_t RCC_APB2Periph_GPIO;

    if (IndexToPort (GPIO_Port, &GPIO) == GPIO_ERROR)
        return GPIO_ERROR;
    GPIO_Pins = GPIO_Pins & GPIO_Available_Pins[GPIO_Port]; // removing from the mask all of the forbidden pins on the selected Port


    switch (GPIO_Port)
    {
        case GPIO_PORTA:
            RCC_APB2Periph_GPIO = RCC_APB2Periph_GPIOA;
        break;
        case GPIO_PORTC:
            RCC_APB2Periph_GPIO = RCC_APB2Periph_GPIOC;
        break;
        case GPIO_PORTD:
            RCC_APB2Periph_GPIO = RCC_APB2Periph_GPIOD;
        break;
        default:
            RCC_APB2Periph_GPIO = 0;
            return GPIO_ERROR;
        break;
    }

    RCC_APB2PeriphClockCmd(RCC_APB2Periph_GPIO, ENABLE);    // enable GPIO clock

    GPIO_InitTypeDef GPIO_InitStructure;
    GPIO_InitStructure.GPIO_Speed = GPIO_Speed_50MHz;

    if ((GPIO_PullUp & 0x8000) && (GPIO_Pins & GPIO_Directions)) {
        GPIO_InitStructure.GPIO_Pin = GPIO_Pins & GPIO_Directions;
        GPIO_InitStructure.GPIO_Mode = GPIO_Mode_IN_FLOATING;
        GPIO_Init(GPIO, &GPIO_InitStructure);
        // LOG_DEBUG("IF 0x%02x " EOL, GPIO_InitStructure.GPIO_Pin);
        return GPIO_SUCCESS;
    }

    GPIO_InitStructure.GPIO_Pin = GPIO_Pins & GPIO_Directions & GPIO_PullUp;
    GPIO_InitStructure.GPIO_Mode = GPIO_Mode_IPU;
    GPIO_Init(GPIO, &GPIO_InitStructure);
    // LOG_DEBUG("IPU 0x%02x " EOL, GPIO_InitStructure.GPIO_Pin);

    GPIO_InitStructure.GPIO_Pin = GPIO_Pins & GPIO_Directions & (~GPIO_PullUp);
    GPIO_InitStructure.GPIO_Mode = GPIO_Mode_IPD;
    GPIO_Init(GPIO, &GPIO_InitStructure);
    // LOG_DEBUG("IPD 0x%02x " EOL, GPIO_InitStructure.GPIO_Pin);

    GPIO_InitStructure.GPIO_Pin = GPIO_Pins & (~GPIO_Directions);
    GPIO_InitStructure.GPIO_Mode = GPIO_Mode_Out_PP;
    GPIO_Init(GPIO, &GPIO_InitStructure);
    // LOG_DEBUG("OUT 0x%02x " EOL, GPIO_InitStructure.GPIO_Pin);
    return GPIO_SUCCESS;
}

GPIO_Error_Type Port_Set_Output (GPIO_PORT_Index GPIO_Port, uint16_t GPIO_Pins, uint16_t GPIO_Value)
{
    GPIO_TypeDef* GPIO;

    if (IndexToPort (GPIO_Port, &GPIO) == GPIO_ERROR)
        return GPIO_ERROR;
    GPIO_Pins = GPIO_Pins & GPIO_Available_Pins[GPIO_Port]; // removing from the mask all of the forbidden pins on the selected Port

    GPIO_SetBits (GPIO, GPIO_Pins & GPIO_Value);
    GPIO_ResetBits (GPIO, GPIO_Pins & (~GPIO_Value));
    return GPIO_SUCCESS;
}

GPIO_Error_Type Port_Get_Input (GPIO_PORT_Index GPIO_Port, uint16_t GPIO_Pins, uint16_t *GPIO_Value)
{
    GPIO_TypeDef* GPIO;

    if (IndexToPort (GPIO_Port, &GPIO) == GPIO_ERROR)
        return GPIO_ERROR;
    GPIO_Pins = GPIO_Pins & GPIO_Available_Pins[GPIO_Port]; // removing from the mask all of the forbidden pins on the selected Port

    *GPIO_Value = (GPIO_ReadInputData (GPIO) & GPIO_Pins);

    if ((INT_Flags[(uint8_t)GPIO_Port] & GPIO_Pins) != 0x00) {
        // Clear IO_EXP_IRQ line
        uint8_t flags = INT_Flags[(uint8_t)GPIO_Port];
        INT_Flags[(uint8_t)GPIO_Port] &= ~GPIO_Pins;
        if (INT_Flags[(uint8_t)GPIO_Port] == 0x00)
            Interrupt_Set_Output();

        // Enable interrupts
        EXTI->INTENR |= (flags & GPIO_Pins);
    }
    return GPIO_SUCCESS;
}
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

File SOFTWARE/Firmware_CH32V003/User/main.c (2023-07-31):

/********************************** (C) COPYRIGHT *******************************
 * File Name          : main.c
 * Author             : WCH
 * Version            : V1.0.0
 * Date               : 2022/08/08
 * Description        : Main program body.
*********************************************************************************
* Copyright (c) 2021 Nanjing Qinheng Microelectronics Co., Ltd.
* Attention: This software (modified or not) and binary are used for 
* microcontroller manufactured by Nanjing Qinheng Microelectronics.
*******************************************************************************/

#include <ch32v00x.h>

#include "Protocol_Decode.h"
#include "Mode_GPIO.h"
#include "Mode_UART.h"
#include "Uptime.h"

/*********************************************************************
 * @fn      main
 *
 * @brief   Main program.
 *
 * @return  none
 */
int main(void)
{
    NVIC_PriorityGroupConfig(NVIC_PriorityGroup_2);
    Uptime_Init();
    Delay_Init();
#ifdef _DEBUG_
    UART_Configure(115200, UART_StopBits_1, UART_Parity_No);
#endif
    LOG_DEBUG("SystemClk: %d" EOL, SystemCoreClock);

    // IO_EXP_IRQ configure - default active high
    Port_Configuration (IO_EXP_IRQ_PORT, IO_EXP_IRQ_PIN, 0x00, 0x00);
    Port_Set_Output (IO_EXP_IRQ_PORT, IO_EXP_IRQ_PIN, 0x00);
    LOG_DEBUG("IO_EXP_IRQ configured" EOL);

    // PWR_SENSE configure
    Port_Configuration (PWR_SENSE_PORT, PWR_SENSE_PIN, PWR_SENSE_PIN, 0x8000);
    Interrupt_Enable(PWR_SENSE_PORT, PWR_SENSE_PINSRC, FRONT_CHANGE);
    LOG_DEBUG("PWR_SENSE configured" EOL);

    // BAT_SENSE configure
    if (ADC_Channel_Init (ADC_TIMEOUT_MS) == GPIO_SUCCESS) {
        LOG_DEBUG("BAT_SENSE configured" EOL);
    } else {
        LOG_DEBUG("BAT_SENSE configuration FAILED" EOL);
    }

    // UEXT Power enable by default
    Port_Configuration (GPIO_PORTC, GPIO_Pin_3, 0x00, 0x00);
    Port_Set_Output (GPIO_PORTC, GPIO_Pin_3, 0x00);
    LOG_DEBUG("UEXT Power ENABLED" EOL);

    SPI_FullDuplex_Init ();

    while (1)
    {
        Wait_For_Command ();
    }
}

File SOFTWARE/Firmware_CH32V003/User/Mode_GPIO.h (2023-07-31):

#ifndef	_MODE_GPIO_H_
#define	_MODE_GPIO_H_

#include <ch32v00x.h>


typedef enum
{
    GPIO_SUCCESS = 0,
    GPIO_ERROR = 1
}GPIO_Error_Type;

typedef enum
{
    GPIO_PORTA = 1,
    GPIO_PORTB = 2,
    GPIO_PORTC = 3,
    GPIO_PORTD = 4
}GPIO_PORT_Index;

typedef enum {
	FRONT_RISING  = 0x01,
	FRONT_FALLING = 0x02,
	FRONT_CHANGE  = 0x03
}GPIO_INT_Trigger;

#define IO_EXP_IRQ_PORT   GPIO_PORTC
#define IO_EXP_IRQ_PIN    GPIO_Pin_4

#define PWR_SENSE_PORT    GPIO_PORTD
#define PWR_SENSE_PIN     GPIO_Pin_0
#define PWR_SENSE_PINSRC  GPIO_PinSource0

#define BAT_SENSE_PORT    GPIO_PORTD
#define BAT_SENSE_PIN     GPIO_Pin_2

#define ADC_TIMEOUT_MS    100

GPIO_Error_Type IndexToPort (GPIO_PORT_Index GPIO_Port, GPIO_TypeDef* *GPIO);

// output 0, input 1
GPIO_Error_Type Port_Configuration (GPIO_PORT_Index GPIO_Port, uint16_t GPIO_Pins, uint16_t GPIO_Directions, uint16_t GPIO_PullUp);
GPIO_Error_Type Port_Set_Output (GPIO_PORT_Index GPIO_Port, uint16_t GPIO_Pins, uint16_t GPIO_Value);
GPIO_Error_Type Port_Get_Input (GPIO_PORT_Index GPIO_Port, uint16_t GPIO_Pins, uint16_t *GPIO_Value);
GPIO_Error_Type Port_Get_Output (GPIO_PORT_Index GPIO_Port, uint16_t GPIO_Pins, uint16_t *GPIO_Value);

GPIO_Error_Type ADC_Channel_Init(uint32_t timeoutMS);
GPIO_Error_Type Get_ADC_Val(uint8_t channel, uint32_t timeoutMS, uint16_t *ADC_Value);
GPIO_Error_Type Get_ADC_Average( uint8_t channel, uint8_t times, uint16_t *ADC_Value);
uint16_t ADC_Map (uint16_t Value, uint16_t MinValue, uint16_t MaxValue, float MinVoltage, float MaxVoltage);

GPIO_Error_Type Interrupt_Level_Set(GPIO_PORT_Index int_active);
void Interrupt_Enable(GPIO_PORT_Index GPIO_PortSourceX, uint8_t GPIO_PinSourceX, GPIO_INT_Trigger trigger);
void Interrupt_Disable(GPIO_PORT_Index GPIO_PortSourceX, uint8_t GPIO_PinSourceX);
uint8_t Interrupt_Flags(GPIO_PORT_Index GPIO_PortSourceX);
uint8_t Interrupt_Capture(GPIO_PORT_Index GPIO_PortSourceX);

void UART_Interrupt_Set();
void UART_Interrupt_Clear();

void EXTI7_0_IRQHandler(void) __attribute__((interrupt("WCH-Interrupt-fast")));
void EXTI7_0_IRQHandler(void);

#endif

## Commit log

2023-07-03 CH32V003 and WiiNunchuk drivers
2023-07-04 Update
    Schematic and design
    [ALSRobot-BUZZER.step, Audio_Jack-3.5mm---CUI_SJ1-3515-SMT-TR.step, BAT54.step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]
2023-08-01 CH32V003 expander improvements
    [partitions.csv]
2023-12-06 adding stl files and 3mf project for 3d printable case
    [esp32-sbc-fabgl-revsion-A-bottom-v1.stl, esp32-sbc-fabgl-revsion-A-top-v1.stl, esp32-sbc-fabgl-revsion-A-v1.3mf]
2024-04-25 Update
    Added manual and next revision changes
    [ALSRobot-BUZZER.step, Audio_Jack-3.5mm---CUI_SJ1-3515-SMT-TR.step, BAT54.step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]

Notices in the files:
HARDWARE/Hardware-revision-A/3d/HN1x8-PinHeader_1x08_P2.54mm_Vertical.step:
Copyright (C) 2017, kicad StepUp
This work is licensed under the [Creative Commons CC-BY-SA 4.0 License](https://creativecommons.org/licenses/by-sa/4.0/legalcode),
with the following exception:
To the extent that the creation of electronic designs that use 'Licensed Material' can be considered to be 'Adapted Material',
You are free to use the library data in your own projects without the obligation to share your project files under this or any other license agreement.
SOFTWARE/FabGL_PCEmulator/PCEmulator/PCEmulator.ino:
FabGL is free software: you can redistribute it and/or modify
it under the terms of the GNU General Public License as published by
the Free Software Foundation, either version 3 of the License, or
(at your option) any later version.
